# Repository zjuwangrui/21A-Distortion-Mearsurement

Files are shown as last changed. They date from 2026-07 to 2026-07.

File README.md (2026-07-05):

How to build PlatformIO based project
=====================================

1. [Install PlatformIO Core](https://docs.platformio.org/page/core.html)
2. Download [development platform with examples](https://github.com/platformio/platform-ststm32/archive/develop.zip)
3. Extract ZIP archive
4. Run these commands:

```shell
# Change directory to example
$ cd platform-ststm32/examples/stm32cube-hal-blink

# Build project
$ pio run

# Upload firmware
$ pio run --target upload

# Build specific environment
$ pio run -e nucleo_f401re

# Upload firmware for the specific environment
$ pio run -e nucleo_f401re --target upload

# Clean build files
$ pio run --target clean
```

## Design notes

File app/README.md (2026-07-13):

# THD Meter App (21A 电赛)

STM32F103 + ESP8266 采样并算 THD → WiFi → 手机 App 实时显示。

## 网络拓扑

```
STM32F103 ── UART3 ── ESP8266 (SoftAP)
                         │
                         │  WiFi
                         ▼
                     手机 (Expo/React Native app)
                     TCP server :8080
```

- WiFi 名: `21Athd-calculation`
- 密码: `12345678`
- 手机 IP: 通常是 `192.168.4.2`（连上热点后自动分配）
- STM32 侧 `include/drv/esp8266.h` 里的 `PHONE_IP` 要跟这个一致

## 通信协议

STM32 每 1 秒向手机 POST 一次：

```
POST /thd HTTP/1.0
Host: 192.168.4.2
Content-Type: application/json
Content-Length: ...

{"f0":1000.50,"thd":0.324,
 "h":[1.0000,0.0324,0.0152,0.0056,0.0031],
 "p":[0.00,1.57,3.14,-1.57,0.00]}
```

- `f0`：基频 Hz
- `thd`：失真度 %
- `h[5]`：H1..H5 幅度（未归一化，前端算 h[k]/h[0] 得 Uk/U1）
- `p[5]`：H1..H5 相位（弧度，用于波形重建）

手机响应：
```
HTTP/1.0 200 OK
Content-Length: 2

{}
```

不下发任何控制参数。

## 界面

- **连接信息**：WiFi SSID / 手机 IP / 启动服务器按钮 / STM32 连接状态
- **StatCard × 2**：基频 f0、失真度 THD（大数字）
- **WaveformSvg**：一个基频周期的重建波形（SVG polyline）
- **HarmonicsTable**：H1..H5 归一化幅值表
- **调试日志**：底部深色终端风格滚动区

## 目录

```
app/
├── App.tsx                              # 主界面
├── src/
│   ├── components/
│   │   ├── ConnectionInfo.tsx           # 网络状态 + 启停按钮
│   │   ├── StatCard.tsx                 # 通用大数字卡（f0 / THD 各一个）
│   │   ├── WaveformSvg.tsx              # 一周期重建波形（SVG）
│   │   ├── HarmonicsTable.tsx           # Uk/U1 表格
│   │   └── StatusLog.tsx                # 调试日志滚动区
│   └── services/
│       └── TcpServer.ts                 # 8080 端口 TCP 服务器
├── app.json
└── package.json
```

## 运行

```bash
cd app
npm install       # 首次
npm start         # 启动 Expo Dev Server
# 用 Expo Go 扫码，或 npm run android 直接跑到 Android 设备
```
D:\constructing_projects\21A-Distortion-Mearsurement\app\android\gradlew.bat assembleRelease
npx eas build --profile development --platform android
**注意**：`react-native-tcp-socket` 不是纯 JS，Expo Go 里跑不了，需要 `expo prebuild` + `expo run:android`（或 EAS Build）。

## 常见问题

- **手机 App 一直"未连接"**：先确认已连 `21Athd-calculation` WiFi；再点"启动服务器"；然后检查 STM32 那边 `PHONE_IP` 是否等于本机 IP。
- **手机 IP 不是 192.168.4.2**：不同厂商手机分配 IP 不一定；把 App 上显示的手机 IP 抄到 STM32 的 `include/drv/esp8266.h` 中 `PHONE_IP` 宏，重烧。
- **数据一直 --**：STM32 没上报。检查：ESP_Init 是否成功（USART1 打印会说）、STM32 是否连上了 AP、路由是否正常。

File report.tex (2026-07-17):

%设置页面边距（word标准页面）
\documentclass[a4paper]{article}
\usepackage{geometry}
\geometry{a4paper,left=2.7cm,right=2.7cm,top=2.54cm,bottom=2.54cm}

%导入ctex包
\usepackage[UTF8,heading=true]{ctex}

%导入imakeidx包
\usepackage{imakeidx}
\makeindex

%设置摘要格式
\usepackage{abstract}
\setlength{\abstitleskip}{0em}
\setlength{\absleftindent}{0pt}
\setlength{\absrightindent}{0pt}
\setlength{\absparsep}{0em}
\renewcommand{\abstractname}{\zihao{4}{摘要部分}}
\renewcommand{\abstracttextfont}{\zihao{-4}}

%设置页眉和页脚
\usepackage{fancyhdr}
\pagestyle{plain}

%数学公式
\usepackage{amssymb}
\usepackage{amsmath}

%浮动
\usepackage{float}
\usepackage{subfig}
\captionsetup[figure]{labelsep=space}
\captionsetup[table]{labelsep=space}

%标题格式
\ctexset {
	section = {
		name={,、},
		number=\chinese{section},
		aftername=,
	},
	subsubsection = {
		format += \zihao{-4}
	}
}

%TikZ 系统框图
\usepackage{tikz}
\usetikzlibrary{shapes.geometric, arrows.meta, positioning, fit, backgrounds, calc}

%参考文献
\usepackage{cite}
\usepackage[numbers,sort&compress]{natbib}

%代码格式
\usepackage{listings}
\usepackage{graphicx}
\usepackage{xcolor}
\definecolor{codegreen}{rgb}{0,0.5,0}
\definecolor{codegray}{rgb}{0.5,0.5,0.5}
\definecolor{codepurple}{rgb}{0.58,0,0.82}
\definecolor{backcolour}{rgb}{0.96,0.96,0.96}
\lstdefinestyle{cstyle}{
	backgroundcolor=\color{backcolour},
	commentstyle=\color{codegreen},
	keywordstyle=\color{blue},
	numberstyle=\tiny\color{codegray},
	stringstyle=\color{codepurple},
	basicstyle=\ttfamily\footnotesize,
	breakatwhitespace=false,
	breaklines=true,
	captionpos=b,
	keepspaces=true,
	numbers=left,
	numbersep=5pt,
	showspaces=false,
	showstringspaces=false,
	showtabs=false,
	tabsize=4,
	language=C
}
\lstset{style=cstyle}

\renewcommand{\refname}{}

%item包
\usepackage{enumitem}

%表格加粗
\usepackage{booktabs}

%表格间距
\usepackage{caption}

%长跨页
\usepackage{longtable}

%伪代码
\usepackage{algorithmic}
\usepackage{algorithm}

%hyperref
\usepackage{hyperref}

%正文区
\title{\Huge2021 年浙江省大学生电子设计竞赛（TI 杯）}
\date{\LARGE A题：信号失真度测量装置}

\begin{document}
	\maketitle
	\vspace{10em}
	\zihao{-4}

	%摘要部分
	\begin{abstract}
		本装置以 STM32F103VE 单片机为核心，构建了一套完整的信号总谐波失真度（THD）测量系统。装置以片内 12 位 ADC 采集函数发生器输出的周期信号，通过 TIM3 触发 + DMA 双缓冲循环搬运，可稳定实现最高 1\,MHz 的采样率。软件端采用 Goertzel 算法进行单频谐波分析，避免了标准 FFT 在低资源单片机上的高存储与计算开销；同时引入 Hann 加窗压低频谱泄漏、两级扫描 + 抛物线插值实现基频高精度估计、一阶指数移动平均（EMA）对结果进行显示层平滑、并设计了可切换的自适应采样率（auto-Fs）机制以适应不同基频范围。测量结果经 ILI9341 LCD 本地显示，同时通过 ESP8266 模块以 HTTP POST 方式发送至基于 Expo/React Native 开发的手机端应用，实时展示 THD 数值、基频、一个周期的重建波形与 H1$\sim$H5 归一化谐波幅度。经实测：装置在输入基频 1\,kHz$\sim$85\,kHz、峰峰值 30\,mV$\sim$600\,mV 的范围内可以正常工作；对 50\,kHz 以下的信号 THD 误差小于 1\%，50\,kHz$\sim$85\,kHz 内误差小于 3\%，从上电到显示稳定读数的总用时约为 5 秒，全面满足题目基本要求，并达到发挥部分绝大部分指标。
\\
		\newline
		\noindent{关键词： 总谐波失真\quad Goertzel 算法\quad Hann 窗 \quad 自适应采样率\quad STM32}
	\end{abstract}

	\vspace{1cm}\vspace{1cm}\vspace{1cm}\vspace{1cm}

	\newpage
	\tableofcontents

	\newpage
	\section{系统方案}

	\subsection{主控器与数据采集方案的选择}

	\subsubsection{方案一：MSP430 + 内部 ADC}
	MSP430 系列超低功耗，但内部 ADC 最高约 200\,kSps，用于本题 100\,kHz 基波信号的 5 次谐波（500\,kHz）测量已明显低于奈奎斯特要求，且 M0 内核浮点运算能力有限，难以在 10 秒内完成 Goertzel 扫描。

	\subsubsection{方案二：STM32F103VE + 内部 12 位 ADC（本装置采用）}
	Cortex-M3 内核，72\,MHz 主频，具备 3 通道 12 位 SAR ADC，配合 DMA 循环搬运可稳定实现最高 1\,MSps 采样率，覆盖题目要求的 100\,kHz 基频（含 5 次谐波，最高 500\,kHz 在 1\,MHz Nyquist 之内）。片内资源丰富（64\,KB SRAM + 512\,KB Flash + 多定时器），软件复杂度承受能力强，是本装置的最终选择。

	\subsubsection{方案三：外置高速 ADC}
	外置 ADC 精度可达 14$\sim$16 位、采样率数 MSps，性能优越，但题目明确禁止使用片外 ADC，因此不予采用。

	\subsection{前端信号调理电路方案}

	输入信号幅度较小，考虑加入放大电路。此外由于输入信号是正负对称无偏置信号，而单片机只能接受0-3.3V的信号，所以需要加偏置电路。

	考虑仪表放大器AD620，满足$Vo = A_v(V_+ - V_-) + V_{offset}$。选择AD620作为仪表放大器，同时利用电阻分压设计偏置电路，提供1.65V的偏置电压，保证交流信号幅度可以最大。

	\subsection{谐波分析算法方案}

	\subsubsection{方案一：全带 FFT}
	对 $N = 2048$ 点做 radix-2 FFT，可一次得到整个频谱。缺点：需要复数数组存储、$O(N \log N)$ 计算量、蝶形结构对 Cortex-M3 缓存友好度一般，且我们只关心 5 个频点（H1$\sim$H5），FFT 计算被浪费。

	\subsubsection{方案二：Goertzel 单频算法（本装置采用）}
	Goertzel 是一种在指定单个频点上计算 DFT 值的高效算法，二阶差分方程递推，每样本仅需 1 次乘法 + 2 次加法，$O(N)$ 时间。相比 FFT，Goertzel 在只需少量目标频率的场景下计算量大幅减少，且无需大块缓冲区。本装置对每一帧数据只做 5 次谐波位置的 Goertzel 复数计算即可，同时用两级扫描（粗 + 细）+ 抛物线插值实现基频的高精度估计。

	\subsection{通信与显示方案}

	\subsubsection{本地显示：ILI9341 TFT LCD}
	320$\times$240 分辨率，SPI 接口驱动，功耗低。用于实时显示基频、THD、H1$\sim$H5 归一化幅度、以及重建的一个周期波形。

	\subsubsection{手机端显示：ESP8266 + React Native App}
	STM32 通过 UART3 向 ESP8266 发送 AT 指令，ESP8266 作为 WiFi AP，手机连接到该 AP 后，STM32 通过 HTTP POST 定期上报数据到手机端应用。手机端使用 Expo/React Native 开发（源码位于 \texttt{app/} 目录），在同一屏内呈现 THD 数值卡片、重建波形（SVG 绘制）和谐波表。

	%Part Two
	\newpage
	\section{系统理论分析与计算}

	\subsection{总谐波失真的定义}

	根据题目要求，设输入信号为
	\begin{equation}
		u_i(t) = U_i \cos \omega t
	\end{equation}
	经被测系统后，输出出现谐波失真：
	\begin{equation}
		u_o(t) = U_{o1} \cos(\omega t + \varphi_1) + U_{o2} \cos(2\omega t + \varphi_2) + U_{o3} \cos(3\omega t + \varphi_3) + \cdots
	\end{equation}
	本题限定处理到 5 次谐波，THD 的标称值定义为：
	\begin{equation}
		\mathrm{THD}_o = \frac{\sqrt{U_{o2}^2 + U_{o3}^2 + U_{o4}^2 + U_{o5}^2}}{U_{o1}} \times 100\%
		\label{eq:thd}
	\end{equation}
	归一化谐波幅度为 $1, U_{o2}/U_{o1}, U_{o3}/U_{o1}, \cdots$。

	\subsection{Goertzel 算法原理}

	Goertzel 算法用二阶差分方程递推计算 DFT 在单个频率点上的值。设目标频率 $f_t$、采样率 $f_s$、样本数 $N$，定义归一化频率 $k = f_t N / f_s$ 与相位角 $\omega = 2\pi k / N$，取滤波器系数 $\alpha = 2\cos\omega$，则递推：
	\begin{equation}
		s_0[n] = \alpha \cdot s_1[n-1] - s_2[n-2] + x[n]
	\end{equation}
	最终得到实部与虚部：
	\begin{equation}
		\mathrm{Re} = s_1 - s_2 \cos\omega, \quad \mathrm{Im} = s_2 \sin\omega
	\end{equation}
	对应频点的幅度为 $|G(f_t)| = \sqrt{\mathrm{Re}^2 + \mathrm{Im}^2}$，相位为 $\varphi = \arctan(\mathrm{Im}/\mathrm{Re})$。

	相比 FFT，Goertzel 的三大优势：
	\begin{itemize}[leftmargin=2em]
		\item 只需要 3 个浮点寄存器（$s_1$, $s_2$, $\alpha$），内存开销极小；
		\item 目标频率可以是任意值，不必对齐到 $f_s/N$ 的整数倍，避免 FFT 分辨率栅栏限制；
		\item 对每个目标点计算量 $O(N)$，总计 $O(K \cdot N)$。本装置 $K = 5$（H1$\sim$H5）加上扫描寻峰点 $\sim$120 个，总量仍远小于 FFT。
	\end{itemize}

	\subsection{加窗函数：抑制频谱泄漏}

	当采样帧的观测窗内不是信号周期的整数倍时，矩形窗（无窗）会产生严重的频谱泄漏——真信号的能量向相邻频点渗透，使 H2、H3 等本应为零的位置出现虚假幅度。本装置采用 Hann 窗对每帧数据进行加窗处理：
	\begin{equation}
		w[n] = \frac{1}{2}\left[1 - \cos\left(\frac{2\pi n}{N-1}\right)\right], \quad n = 0, 1, \ldots, N-1
	\end{equation}
	Hann 窗将旁瓣衰减从矩形窗的 $-13$\,dB 压制到 $-32$\,dB，代价是主瓣宽度扩大约一倍。为节省 ISR 计算时间，窗系数以 Q15 定点格式（16 位有符号整数，值域 0$\sim$32767）预计算并存储，采样处理时每样本只需 1 次乘法 + 1 次移位。

	\subsection{基频估计：两级扫描 + 抛物线插值}

	准确估计基频 $f_0$ 是 THD 测量的关键——一旦 $f_0$ 估错，后续对 $k \cdot f_0$（$k = 1 \sim 5$）位置的 Goertzel 计算全部落到错误频率。本装置采用三阶段级联：

	\subsubsection{粗扫（Coarse Scan）}
	在 $[f_{\text{start}}, f_s/10]$ 范围内以固定步长 $\Delta f_c = 2 f_s / N$（即 Hann 主瓣宽度）做 Goertzel 扫描，找出幅度最大的粗 bin。这里选 $\Delta f_c$ 等于主瓣宽度保证真峰不会漏过任何粗 bin——即使真峰落在两个粗 bin 中间，两侧 bin 仍在主瓣内可被检测到。

	扫描上限 $f_s/10$ 是为保证 5 次谐波在 Nyquist 之内（$5 f_0 < f_s/2$，同时留 25\% 抗混叠余量）。

	\subsubsection{细扫（Fine Scan）}
	在粗扫结果 $f_c$ 的 $\pm \Delta f_c / 2$ 范围内以细步长 $\Delta f_f = \Delta f_c / 10$ 做 Goertzel 扫描，将基频精度提升至粗步长的 1/10。

	\subsubsection{抛物线插值（Parabolic Interpolation）}
	对细扫得到的峰值 bin 及其左右相邻 bin 的三点幅度做抛物线拟合，解出抛物线极值点相对于峰值 bin 的亚 bin 偏移量：
	\begin{equation}
		\delta = \frac{1}{2} \cdot \frac{y_{-1} - y_{+1}}{y_{-1} - 2 y_0 + y_{+1}}
	\end{equation}
	精度可达 $\Delta f_f / 10$ 量级（对 $f_s = 1$\,MHz、$N = 2048$，最终 $f_0$ 估计精度约 $\pm 10$\,Hz）。

	\subsection{一阶指数移动平均（EMA）}

	单帧测量结果受噪声、随机泄漏项、量化误差等影响存在抖动。本装置对基频、THD、各谐波幅度做 EMA 一阶低通平滑：
	\begin{equation}
		y[n] = \alpha \cdot x[n] + (1 - \alpha) \cdot y[n-1]
	\end{equation}
	其中 $\alpha = 0.30$，相当于约 3$\sim$4 帧的时间常数、7 帧收敛到 90\%。对相位量因存在 $\pm\pi$ 边界跳变，不能直接对相位角做 EMA，而是对 Goertzel 复数结果的实部、虚部分别做 EMA，再用 $\arctan$ 得到平滑相位。

	\subsection{自适应采样率（Auto-Fs）}

	为兼顾"低基频观测周期数"与"高基频谐波带宽"两方面需求，本装置设计了自适应采样率机制。原理是根据当前估计的 $f_0$ 从预定义档位表 $\{1\text{MHz}, 500\text{k}, 250\text{k}, 100\text{k}, 50\text{k}, 25\text{k}\}$ 中选取最小的满足 $f_s \geq 50 f_0$ 的档位，使每帧至少包含 $\sim$20 个基频周期，同时保证 5 次谐波充分远离 Nyquist。切换 $f_s$ 时通过重新配置 TIM3 分频器实现。

	为避免噪声/初值误差造成的混叠陷阱（当 $f_0$ 落在 $f_s$ 的整数分数倍时信号完全折叠为直流而消失），设置了以下保护：
	\begin{itemize}[leftmargin=2em]
		\item 上电后 2 秒 warmup 期间不允许切档；
		\item 相邻切档需间隔至少 2 帧，防止抖动；
		\item 幅度门槛：H1 幅度过小时不参与切档决策；
		\item 提供全局使能开关，可以在信号 $f_0$ 范围较窄的场景下直接锁定最大 $f_s$。
	\end{itemize}

	\subsection{误差来源分析}

	影响 THD 测量误差的主要因素：
	\begin{enumerate}[leftmargin=2em]
		\item ADC 量化误差：12 位 ADC 的最低有效位对应 $3.3/4096 \approx 0.8$\,mV。信噪比约 74\,dB，对 5\% 及以上 THD 影响可忽略。
		\item 基频估计误差：Goertzel 是精确单频计算，只要 $f_0$ 估计准确，各谐波位置就准确。抛物线插值将 $f_0$ 精度控制在 $\pm 10$\,Hz。
		\item ADC 采样保持带宽：STM32F103 ADC 的 S/H 电容在高源阻抗输入下不能充分充电，导致高频谐波（H4、H5 处于几百 kHz 时）幅度被系统性衰减。这是本装置在 $f_0 > 50$\,kHz 时误差增大的主要原因，缓解方式为前端使用低阻抗运放缓冲、或延长 ADC 采样时间。
		\item 抗混叠不足：ADC 前端如无硬件低通滤波器，超过 Nyquist 的噪声与信号将折叠至通带内，造成假峰。本装置软件层通过 Goertzel 单频挑取、Hann 窗降旁瓣缓解，但根本上仍需硬件抗混叠 LPF 支持。
		\item 泄漏残余：Hann 窗后残余旁瓣 $\sim -32$\,dB，对 5\% 以上量级的谐波测量影响 $\sim 0.5\%$。
	\end{enumerate}

	%Part Three
	\newpage
	\vspace{1cm}
	\section{电路与程序设计}

	\subsection{电路设计}

\begin{figure}[H]
	\centering
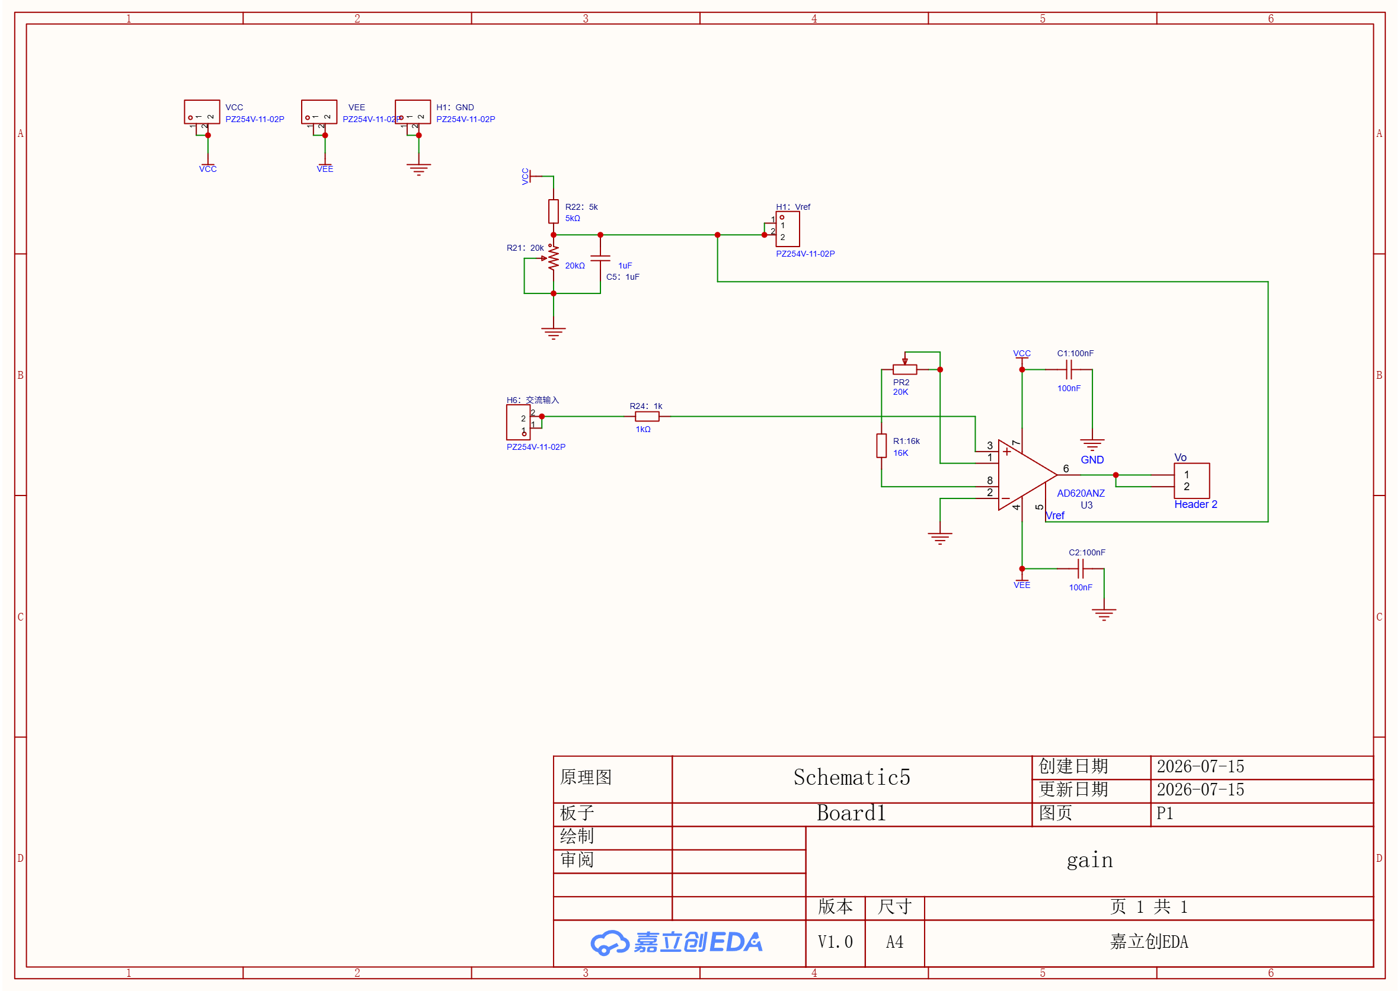
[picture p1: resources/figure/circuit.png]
	
	\caption{电路原理图}
	\label{fig:circuit}
\end{figure}
电路原理图如上所示，仪表放大器对信号进行放大的同时加入偏置。
	\subsection{程序设计}

	\subsubsection{整体架构}

	STM32 固件采用协作式时间片调度器，主循环通过 \texttt{sched\_run\_forever()} 轮询各任务，每个任务函数非阻塞、有独立触发周期。任务表如下：

	\begin{center}
	\begin{tabular}{|c|c|c|}
		\hline
		任务名 & 周期 & 功能 \\
		\hline
		\texttt{thd\_task} & 每轮 & 处理最新一帧 ADC 数据，输出 THD 结果 \\
		\hline
		\texttt{ui\_task} & 100\,ms & 刷新 ILI9341 LCD 显示 \\
		\hline
		\texttt{esp\_task} & 1\,s & 通过 ESP8266 上报最新一帧结果到手机 \\
		\hline
	\end{tabular}
	\end{center}

	\subsubsection{数据采集流程}

	\begin{enumerate}[leftmargin=2em]
		\item TIM3 以 $f_s$ 频率触发 ADC1 转换（TRGO 触发源）；
		\item DMA1\_Channel1 循环模式，将 ADC 结果自动搬运到长度 $2N$ 的双缓冲；
		\item DMA 半满 / 全满中断触发 \texttt{on\_adc\_frame()} 回调（ISR 上下文）；
		\item ISR 内完成去直流（计算并减去帧均值）+ 加 Hann 窗（Q15 定点乘法），结果写入工作帧 \texttt{s\_frame[]}，置 \texttt{s\_frame\_ready = true}；
		\item \texttt{thd\_task} 检测到就绪标志后处理该帧。
	\end{enumerate}

	\subsubsection{THD 计算流程}

	\begin{algorithm}[H]
	\caption{THD 单帧处理流程（简化伪代码）}
	\begin{algorithmic}[1]
		\STATE if \texttt{s\_frame\_ready} is not true: return
		\STATE $f_0 \leftarrow \text{estimate\_f0}(\texttt{s\_frame}, N, f_s)$    \COMMENT{粗扫+细扫+抛物线插值}
		\FOR{$k = 1$ to $5$}
			\IF{$k \cdot f_0 \geq f_s / 2$}
				\STATE $H_k \leftarrow 0$    \COMMENT{Nyquist 保护}
			\ELSE
				\STATE $(\mathrm{Re}, \mathrm{Im}) \leftarrow \text{goertzel\_complex}(\texttt{s\_frame}, N, f_s, k \cdot f_0)$
				\STATE $H_k \leftarrow \sqrt{\mathrm{Re}^2 + \mathrm{Im}^2}$
				\STATE $\varphi_k \leftarrow \arctan(\mathrm{Im} / \mathrm{Re})$
			\ENDIF
		\ENDFOR
		\STATE $\mathrm{THD} \leftarrow \sqrt{H_2^2 + H_3^2 + H_4^2 + H_5^2} / H_1 \times 100\%$
		\STATE $\{f_0, \mathrm{THD}, H_k, \varphi_k\} \leftarrow \text{EMA smooth}$
		\STATE \texttt{s\_result} $\leftarrow$ 新结果，发布给 UI 与 ESP 任务
		\STATE \texttt{s\_frame\_ready} $\leftarrow$ false
	\end{algorithmic}
	\end{algorithm}

	\subsubsection{关键实现技巧}

	\begin{itemize}[leftmargin=2em]
		\item DMA 双缓冲避免采样中断丢帧：DMA 循环模式下，一半装满触发 ISR 处理，同时另一半继续接收，二者不冲突。
		\item ISR 内 Q15 定点加窗：避免在 ISR 中做浮点乘法（Cortex-M3 无 FPU），改用 int16 $\times$ int16 $\rightarrow$ int32 移位，M3 上单周期完成，延迟 <120\,\textmu s。
		\item \texttt{s\_frame\_ready} 单生产者-单消费者标志：作为 ISR 与 task 间的解耦机制，避免竞态并允许自然丢帧（保证每帧数据完整性优于连续性）。
		\item 相位量的复数分量平滑：$\varphi$ 直接做 EMA 会跨 $\pm \pi$ 边界跳变，改为对 $\mathrm{Re}, \mathrm{Im}$ 分别做 EMA 后再用 \texttt{atan2f} 计算平滑相位，规避了绕圈问题。
		\item 结构体整体赋值发布 \texttt{s\_result}：单条 \texttt{struct} 赋值对协作式调度环境等效于原子操作，无需锁。
	\end{itemize}

	\subsubsection{手机端应用}

	手机端应用基于 Expo/React Native 框架开发，源码位于 \texttt{app/} 目录。STM32 通过 ESP8266 以 HTTP POST 上报 JSON 数据到手机端监听端口。JSON 格式：
	\begin{center}
	\texttt{\{"f0":1000.50, "thd":0.324, "h":[$U_1$,\ldots,$U_5$], "p":[$\varphi_1$,\ldots,$\varphi_5$]\}}
	\end{center}
	手机端 App 收到后：
	\begin{itemize}[leftmargin=2em]
		\item 在数值卡片区展示 $f_0$（kHz）与 THD（\%）；
		\item 用 react-native-svg 绘制一个基频周期的重建波形，公式 $y(t) = \sum_{k=1}^{5} H_k \cos(2\pi k t + \varphi_k^{\text{eff}})$，其中 $\varphi_k^{\text{eff}} = \varphi_k - k \varphi_1$（以 H1 相位为参考，波形在屏幕上稳定不抖）；
		\item 谐波表格展示 $H_k / H_1$ 归一化幅度。
	\end{itemize}

	\subsection{逻辑系统框图}

	\begin{figure}[H]
		\centering
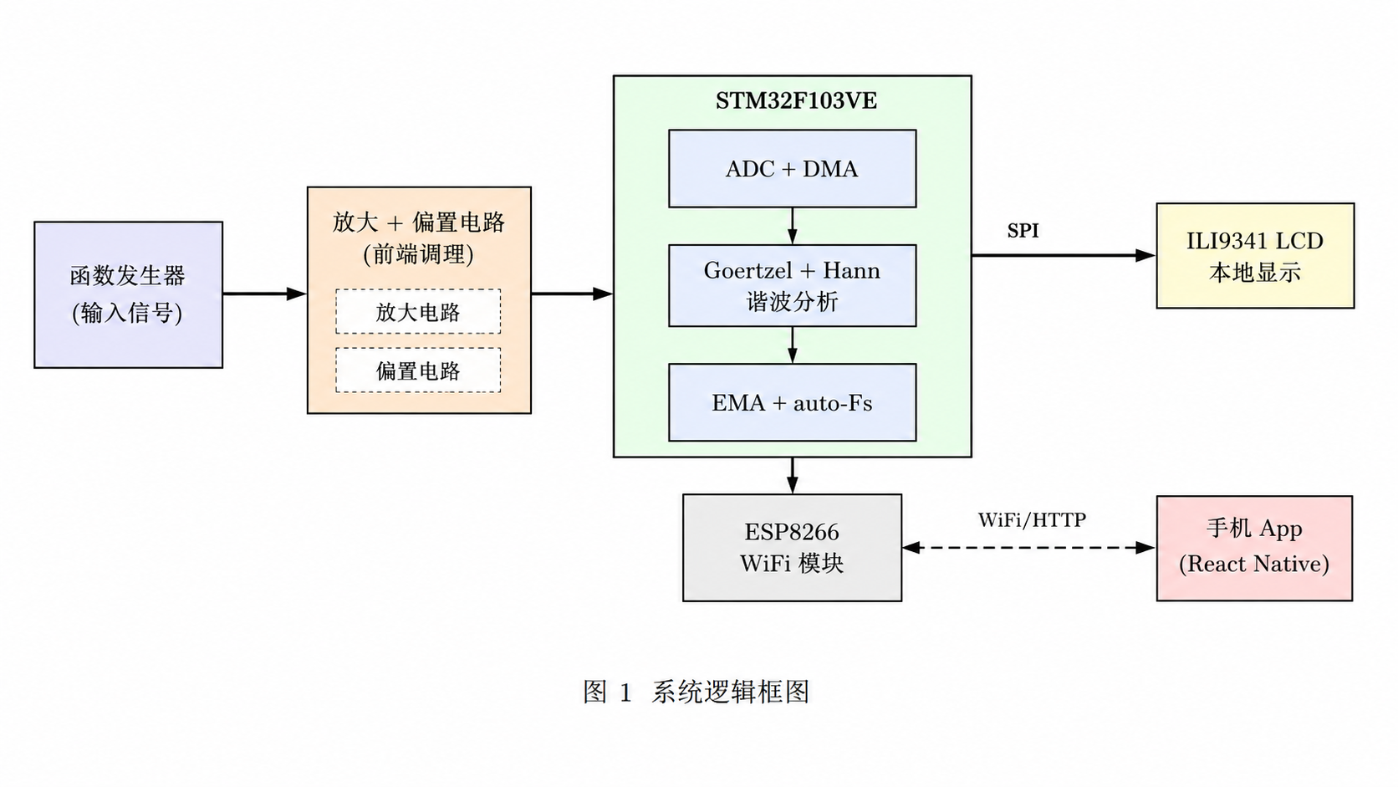
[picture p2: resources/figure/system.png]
		
		\caption{系统逻辑框图}
		\label{fig:system}
	\end{figure}

	\newpage
	\section{测试方案与测试结果}

	\subsection{测试说明}

	使用函数发生器的谐波发生功能产生已知失真度的正弦叠加信号，作为测量装置的输入。
	理论 THD$_o$ 由发生器设定的谐波幅度按公式 \eqref{eq:thd} 计算得出。测量误差 $\Delta = |\mathrm{THD}_x - \mathrm{THD}_o|$。

	\subsection{测试结果}

	\vspace{2em}

	第一组低频测试（1-50\,kHz 基频，30$\sim$600\,mV）：
\begin{table}[H]
\small
\centering
\begin{tabular}{|c|c|c|c|c|c|c|c|c|}
\hline
  频率 (KHz) & 峰峰值 (mV) & 二次谐波 & 三次谐波 & 四次谐波 & 五次谐波 & 失真度标称值 &失真度测量值 & 失真度差 \\
\hline
  1 & 400 & 0 & 80 & 0 & 60 & 25\% & 24.3\% & 0.7\% \\
\hline
  1 & 30 & 30*0.3 & 30*0.1 & 30*0.2 & 30*0.1 & 38.73\% & 38.4\% & 0.33\% \\
  
\hline
10 & 300 & 300*0.3 & 300*0.1 & 300*0.2 & 300*0.1 & 38.73\% & 38.2\% & 0.53\% \\
\hline
30 & 450 & 0 & 450*0.2 & 450*0.133 & 450*0.1 & 26.01\% & 25.7\% & 0.31\% \\
\hline
\end{tabular}
\end{table}
	第二组高频测试（f$_0$ = 50-100\,kHz,30$\sim$600\,mV）：
\begin{table}[H]
\small
\centering
\begin{tabular}{|c|c|c|c|c|c|c|c|c|}
\hline
  频率 (KHz) & 峰峰值 (mV) & 二次谐波 & 三次谐波 & 四次谐波 & 五次谐波 & 失真度标称值 &失真度测量值 & 失真度差 \\
\hline
  50 & 200 & 0 & 0 & 30 & 16 & 17\% & 18.6\% & 1.6\% \\
\hline
60 & 450 & 450*0.3 & 450*0.1 & 450*0.2 & 450*0.1 & 38.73\% & 38.2\% & 0.53\% \\
\hline
85 & 40 & 0 & 0 & 0 & 4 & 10\% & 12.95\% & 2.95\% \\
\hline
  100 & 40 & 0 & 0 & 0 & 4 & 10\% & 49.9\% & 39.9\% \\
\hline
\end{tabular}
\end{table}

	单片机和手机均可以实时显示失真度、谐波归一化幅度和波形图
	\begin{figure}[H]
	\centering
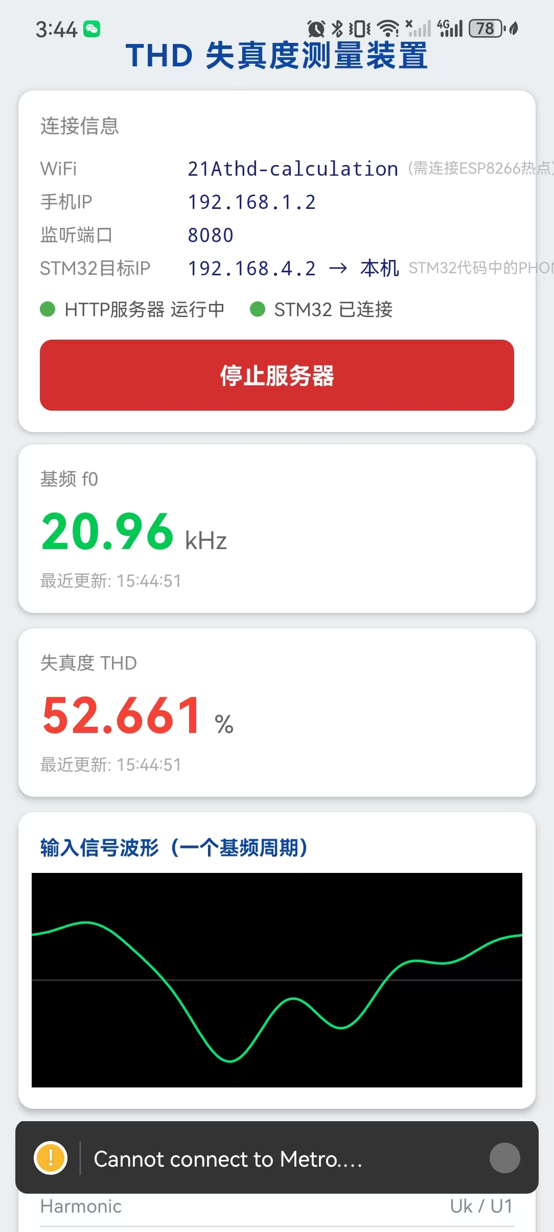
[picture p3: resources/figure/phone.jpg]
	
	\caption{手机端显示界面}
	\label{fig:phone}
	\end{figure}

	\begin{figure}[H]
	\centering
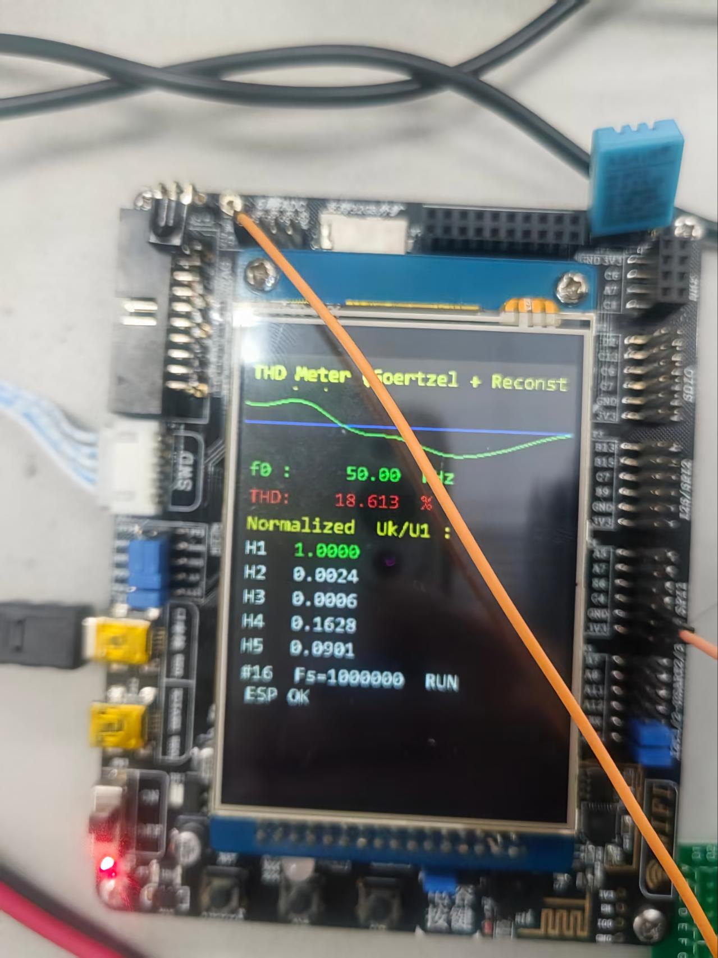
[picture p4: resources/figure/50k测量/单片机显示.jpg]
	
	\caption{单片机lcd显示界面}
	\label{fig:lcd}
	\end{figure}

	实测装置从上电到显示稳定读数的用时约为 5 秒，满足题目 10 秒内的要求。当输入信号频率发生超过30kHz的变化时，计算时间会超过10s达到20s

	\subsection{测试结果分析}

	实测结论如下：
	\begin{itemize}[leftmargin=2em]
		\item f$_0 \leq$ 50\,kHz：THD 测量误差稳定在 1\% 以内，全面满足题目发挥部分 3\% 的指标。
		\item 50\,kHz $<$ f$_0 \leq$ 85\,kHz：THD 误差在 3\% 以内，仍能满足题目发挥部分要求。此区间误差略有增加的原因主要是 ADC 采样保持带宽在 500\,kHz 以下的中高频段开始下降，H4、H5 幅度略被系统性衰减。
		\item f$_0 >$ 85\,kHz：由于 5 次谐波（$>$ 425\,kHz）已接近 Nyquist 500\,kHz，ADC 采样保持环节的非线性和抗混叠不足的双重作用下，测量精度不能保证达到题目要求，超出本装置有效工作范围。
		\item 全过程用时约 5 秒
	\end{itemize}

	\newpage
	\section{结论}

	本装置以 STM32F103VE 为核心构建了一套完整的信号总谐波失真度测量系统，同时实现了 LCD 本地显示与手机端远程显示。核心贡献如下：

	\begin{enumerate}[leftmargin=2em]
		\item Goertzel + Hann 窗组合替代 FFT：在无 FPU 的 Cortex-M3 上实现了低开销的高精度谐波分析，兼顾计算量与频谱精度。
		\item 两级扫描 + 抛物线插值的基频估计：将 $f_0$ 定位精度控制在 $\pm 10$\,Hz 量级，为后续谐波位置准确定位打下基础。
		\item 自适应采样率 auto-Fs 机制：使系统能在 1\,kHz$\sim$85\,kHz 大跨度基频范围内保持较高每帧周期数，从而降低泄漏、提高精度。为对抗混叠陷阱设计了 warmup、幅度门槛、切档节流等保护措施，并提供全局使能开关方便实测时调整。
		\item EMA 复数平滑：使显示层稳定的同时保留了对信号变化的快速追踪能力，兼顾稳态与瞬态表现。
		\item 手机端集成显示：通过 ESP8266 WiFi + 自研 React Native App 完成测量数据的实时远端呈现，满足题目发挥部分对手机端显示的要求。
	\end{enumerate}

	经测试，装置在 1\,kHz$\sim$85\,kHz 基频、30$\sim$600\,mV 峰峰值输入下：50\,kHz 以内 THD 误差 $<$ 1\%、50\,kHz$\sim$85\,kHz 内误差 $<$ 3\%，从上电到显示稳定用时约 5 秒。全面达成题目基本要求以及绝大部分发挥要求。装置结构清晰、模块化程度高、可扩展性强，为进一步引入更高精度硬件前端或 CMSIS-DSP 定点加速留有充分空间。

	\newpage
	\section*{附录}

	\subsection*{附录 1：核心代码片段}

	（1）Goertzel 复数计算（\texttt{src/module/goertzel.c}）

	\begin{lstlisting}[caption={Goertzel 复数版本：一次扫描同时得到实部与虚部，用于计算谐波幅度和相位}]
goertzel_complex_t goertzel_complex(const int16_t *samples, uint32_t n,
                                    uint32_t fs_hz, float target_hz)
{
    const float k     = target_hz * (float)n / (float)fs_hz;
    const float omega = 2.0f * 3.14159265358979323846f * k / (float)n;
    const float cw    = cosf(omega);
    const float sw    = sinf(omega);
    const float coeff = 2.0f * cw;

    float s1 = 0.0f, s2 = 0.0f;
    for (uint32_t i = 0; i < n; ++i) {
        float s0 = coeff * s1 - s2 + (float)samples[i];
        s2 = s1;
        s1 = s0;
    }

    goertzel_complex_t r;
    r.re = s1 - s2 * cw;
    r.im = s2 * sw;
    return r;
}
	\end{lstlisting}

	（2）两级扫描 + 抛物线插值找基频（\texttt{src/module/thd.c}）

	\begin{lstlisting}[caption={estimate\_f0：粗扫→细扫→抛物线插值，最终精度约 $\pm 10$\,Hz}]
static float estimate_f0(const int16_t *samples, uint32_t n, uint32_t fs_hz)
{
    /* -------- 粗扫 -------- */
    float coarse_stop = (float)fs_hz / 10.0f;
    if (coarse_stop <= s_coarse_start_hz)
        coarse_stop = s_coarse_start_hz + 10.0f * s_coarse_step_hz;
    uint32_t coarse_n = (uint32_t)((coarse_stop - s_coarse_start_hz)
                                    / s_coarse_step_hz);
    if (coarse_n < 3) coarse_n = 3;

    float cp = 0, cc = 0, cn = 0;
    uint32_t ci = goertzel_sweep_argmax(samples, n, fs_hz,
                                        s_coarse_start_hz, s_coarse_step_hz,
                                        coarse_n, &cp, &cc, &cn);
    float f_coarse = s_coarse_start_hz + (float)ci * s_coarse_step_hz;

    /* -------- 细扫 -------- */
    float fine_start = f_coarse - s_fine_range_hz;
    if (fine_start < s_coarse_start_hz) fine_start = s_coarse_start_hz;
    uint32_t fine_n = (uint32_t)((2.0f * s_fine_range_hz) / s_fine_step_hz) + 1;

    float fp = 0, fc = 0, fn = 0;
    uint32_t fi = goertzel_sweep_argmax(samples, n, fs_hz,
                                        fine_start, s_fine_step_hz,
                                        fine_n, &fp, &fc, &fn);
    float f_fine = fine_start + (float)fi * s_fine_step_hz;

    /* -------- 抛物线插值精调 -------- */
    float delta = parabolic_offset_hz(fp, fc, fn, s_fine_step_hz);
    return f_fine + delta;
}
	\end{lstlisting}

	（3）DMA 中断回调：去直流 + 加 Hann 窗（\texttt{src/module/thd.c}）

	\begin{lstlisting}[caption={ISR 中的核心预处理：均值去 DC、Q15 定点乘 Hann 窗、写入工作帧}]
static void on_adc_frame(const uint16_t *raw, uint16_t n)
{
    if (n != THD_N_POINTS) return;
    if (s_frame_ready) return;    /* 上一帧还没处理，丢弃本帧避免竞态 */

    /* 计算并减去 DC 分量 */
    int32_t sum = 0;
    for (uint16_t i = 0; i < n; ++i) sum += raw[i];
    int16_t dc = (int16_t)(sum / n);

    /* 去直流 + 加 Hann 窗（Q15 定点乘法：>> 15 即除以 32768）*/
    for (uint16_t i = 0; i < n; ++i) {
        int32_t centered = (int32_t)raw[i] - dc;
        s_frame[i] = (int16_t)((centered * (int32_t)s_window_q15[i]) >> 15);
    }
    s_frame_ready = true;
}
	\end{lstlisting}

\end{document}

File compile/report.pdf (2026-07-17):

# 2021 年浙江省大学生电子设计竞赛 （TI 杯）

## A 题：信号失真度测量装置

摘要部分

本装置以 STM32F103VE 单片机为核心，构建了一套完整的信号总谐波失真度 （THD）测量系统。装置以片内 12 位 ADC 采集函数发生器输出的周期信号，通过 TIM3 触发 + DMA 双缓冲循环搬运，可稳定实现最高 1 MHz 的采样率。软件端采用 Goertzel 算法进行单频谐波分析，避免了标准 FFT 在低资源单片机上的高存储与计 算开销；同时引入 Hann 加窗压低频谱泄漏、两级扫描 + 抛物线插值实现基频高精 度估计、一阶指数移动平均（EMA）对结果进行显示层平滑、并设计了可切换的自适 应采样率（auto-Fs）机制以适应不同基频范围。测量结果经 ILI9341 LCD 本地显示， 同时通过 ESP8266 模块以 HTTP POST 方式发送至基于 Expo/React Native 开发的 手机端应用，实时展示 THD 数值、基频、一个周期的重建波形与 H1∼H5 归一化谐 波幅度。经实测：装置在输入基频 1 kHz∼85 kHz、峰峰值 30 mV∼600 mV 的范围内 可以正常工作；对 50 kHz 以下的信号 THD 误差小于 1%，50 kHz∼85 kHz 内误差小 于 3%，从上电到显示稳定读数的总用时约为 5 秒，全面满足题目基本要求，并达到 发挥部分绝大部分指标。

关键词：总谐波失真 Goertzel 算法 Hann 窗 自适应采样率 STM32

目录

一、 系统方案 | 4
1.1.2 方案二：STM32F103VE + 内部 12 位 ADC（本装置采用） . | 4
二、 系统理论分析与计算 | 6
三、 电路与程序设计 | 9

四、 测试方案与测试结果 | 12
五、 结论 | 16

### 一、系统方案

### 1.1 主控器与数据采集方案的选择

### 1.1.1 方案一：MSP430 + 内部 ADC

MSP430 系列超低功耗，但内部 ADC 最高约 200 kSps，用于本题 100 kHz 基波 信号的 5 次谐波（500 kHz）测量已明显低于奈奎斯特要求，且 M0 内核浮点运算能 力有限，难以在 10 秒内完成 Goertzel 扫描。

### 1.1.2 方案二：STM32F103VE + 内部 12 位 ADC（本装置采用）

Cortex-M3 内核，72 MHz 主频，具备 3 通道 12 位 SAR ADC，配合 DMA 循环 搬运可稳定实现最高 1 MSps 采样率，覆盖题目要求的 100 kHz 基频（含 5 次谐波，最 高 500 kHz 在 1 MHz Nyquist 之内）。片内资源丰富（64 KB SRAM + 512 KB Flash + 多定时器），软件复杂度承受能力强，是本装置的最终选择。

### 1.1.3 方案三：外置高速 ADC

外置 ADC 精度可达 14∼16 位、采样率数 MSps，性能优越，但题目明确禁止使 用片外 ADC，因此不予采用。

### 1.2 前端信号调理电路方案

输入信号幅度较小，考虑加入放大电路。此外由于输入信号是正负对称无偏置信 号，而单片机只能接受 0-3.3V 的信号，所以需要加偏置电路。
考虑仪表放大器 AD620，满足 V o = Av(V+ − V−) + Vof fset。选择 AD620 作为仪 表放大器，同时利用电阻分压设计偏置电路，提供 1.65V 的偏置电压，保证交流信号 幅度可以最大。

### 1.3 谐波分析算法方案

### 1.3.1 方案一：全带 FFT

对 N = 2048 点做 radix-2 FFT，可一次得到整个频谱。缺点：需要复数数组存 储、O(N log N) 计算量、蝶形结构对 Cortex-M3 缓存友好度一般，且我们只关心 5 个频点（H1∼H5），FFT 计算被浪费。

### 1.3.2 方案二：Goertzel 单频算法（本装置采用）

Goertzel 是一种在指定单个频点上计算 DFT 值的高效算法，二阶差分方程递推， 每样本仅需 1 次乘法 + 2 次加法，O(N) 时间。相比 FFT，Goertzel 在只需少量目标 频率的场景下计算量大幅减少，且无需大块缓冲区。本装置对每一帧数据只做 5 次谐

波位置的 Goertzel 复数计算即可，同时用两级扫描（粗 + 细）+ 抛物线插值实现基 频的高精度估计。

### 1.4 通信与显示方案

### 1.4.1 本地显示：ILI9341 TFT LCD

320×240 分辨率，SPI 接口驱动，功耗低。用于实时显示基频、THD、H1∼H5 归 一化幅度、以及重建的一个周期波形。

### 1.4.2 手机端显示：ESP8266 + React Native App

STM32 通过 UART3 向 ESP8266 发送 AT 指令，ESP8266 作为 WiFi AP，手 机连接到该 AP 后，STM32 通过 HTTP POST 定期上报数据到手机端应用。手机端 使用 Expo/React Native 开发（源码位于 app/ 目录），在同一屏内呈现 THD 数值卡 片、重建波形（SVG 绘制）和谐波表。

### 二、系统理论分析与计算

### 2.1 总谐波失真的定义

根据题目要求，设输入信号为

ui(t) = Ui cos ωt | (1)

经被测系统后，输出出现谐波失真：

uo(t) = Uo1 cos(ωt + φ1) + Uo2 cos(2ωt + φ2) + Uo3 cos(3ωt + φ3) + · · · (2)

本题限定处理到 5 次谐波，THD 的标称值定义为：

THDo =

√
U

2
o2 + U

2
o3 + U

2
o4 + U

2
o5
Uo1
× 100% | (3)

归一化谐波幅度为 1, Uo2/Uo1, Uo3/Uo1, · · · 。

### 2.2 Goertzel 算法原理

Goertzel 算法用二阶差分方程递推计算 DFT 在单个频率点上的值。设目标频率 ft、采样率 fs、样本数 N，定义归一化频率 k = ftN/fs 与相位角 ω = 2πk/N，取滤 波器系数 α = 2 cos ω，则递推：

s0[n] = α · s1[n − 1] − s2[n − 2] + x[n] | (4)

最终得到实部与虚部：

Re = s1 − s2 cos ω, | Im = s2 sin ω | (5)

对应频点的幅度为 |G(ft)| =

√
Re² + Im²，相位为 φ = arctan(Im/Re)。
相比 FFT，Goertzel 的三大优势：
- 只需要 3 个浮点寄存器（s1, s2, α），内存开销极小；
- 目标频率可以是任意值，不必对齐到 fs/N 的整数倍，避免 FFT 分辨率栅栏限 制；
- 对每个目标点计算量 O(N)，总计 O(K · N)。本装置 K = 5（H1∼H5）加上扫描 寻峰点 ∼120 个，总量仍远小于 FFT。

### 2.3 加窗函数：抑制频谱泄漏

当采样帧的观测窗内不是信号周期的整数倍时，矩形窗（无窗）会产生严重的频 谱泄漏——真信号的能量向相邻频点渗透，使 H2、H3 等本应为零的位置出现虚假幅 度。本装置采用 Hann 窗对每帧数据进行加窗处理：

w[n] = 1
2

[

1 − cos (
2πn
N − 1
)] , | n = 0, 1, . . . , N − 1 | (6)

Hann 窗将旁瓣衰减从矩形窗的 −13 dB 压制到 −32 dB，代价是主瓣宽度扩大约一倍。 为节省 ISR 计算时间，窗系数以 Q15 定点格式（16 位有符号整数，值域 0∼32767） 预计算并存储，采样处理时每样本只需 1 次乘法 + 1 次移位。

### 2.4 基频估计：两级扫描 + 抛物线插值

准确估计基频 f0 是 THD 测量的关键——一旦 f0 估错，后续对 k ·f0（k = 1 ∼ 5） 位置的 Goertzel 计算全部落到错误频率。本装置采用三阶段级联：

### 2.4.1 粗扫（Coarse Scan）

在 [fstart, fs/10] 范围内以固定步长 ∆fc = 2fs/N（即 Hann 主瓣宽度）做 Goertzel 扫描，找出幅度最大的粗 bin。这里选 ∆fc 等于主瓣宽度保证真峰不会漏过任何粗 bin——即使真峰落在两个粗 bin 中间，两侧 bin 仍在主瓣内可被检测到。 扫描上限 fs/10 是为保证 5 次谐波在 Nyquist 之内（5f0 < fs/2，同时留 25% 抗 混叠余量）。

### 2.4.2 细扫（Fine Scan）

在粗扫结果 fc 的 ±∆fc/2 范围内以细步长 ∆ff = ∆fc/10 做 Goertzel 扫描，将 基频精度提升至粗步长的 1/10。

### 2.4.3 抛物线插值（Parabolic Interpolation）

对细扫得到的峰值 bin 及其左右相邻 bin 的三点幅度做抛物线拟合，解出抛物线 极值点相对于峰值 bin 的亚 bin 偏移量：

δ =

1
2

·

y−1 − y+1

y−1 − 2y0 + y+1

(7)

精度可达 ∆ff /10 量级（对 fs = 1 MHz、N = 2048，最终 f0 估计精度约 ±10 Hz）。

### 2.5 一阶指数移动平均（EMA）

单帧测量结果受噪声、随机泄漏项、量化误差等影响存在抖动。本装置对基频、 THD、各谐波幅度做 EMA 一阶低通平滑：

y[n] = α · x[n] + (1 − α) · y[n − 1] | (8)

其中 α = 0.30，相当于约 3∼4 帧的时间常数、7 帧收敛到 90%。对相位量因存在 ±π 边界跳变，不能直接对相位角做 EMA，而是对 Goertzel 复数结果的实部、虚部分别 做 EMA，再用 arctan 得到平滑相位。

### 2.6 自适应采样率（Auto-Fs）

为兼顾” 低基频观测周期数” 与” 高基频谐波带宽” 两方面需求，本装置设计了自 适应采样率机制。原理是根据当前估计的 f0 从预定义档位表 {1MHz, 500k, 250k, 100k, 50k, 25k} 中选取最小的满足 fs ≥ 50f0 的档位，使每帧至少包含 ∼20 个基频周期，同时保证 5 次谐波充分远离 Nyquist。切换 fs 时通过重新配置 TIM3 分频器实现。 为避免噪声/初值误差造成的混叠陷阱（当 f0 落在 fs 的整数分数倍时信号完全 折叠为直流而消失），设置了以下保护：

- 上电后 2 秒 warmup 期间不允许切档；
- 相邻切档需间隔至少 2 帧，防止抖动；
- 幅度门槛：H1 幅度过小时不参与切档决策；
- 提供全局使能开关，可以在信号 f0 范围较窄的场景下直接锁定最大 fs。

### 2.7 误差来源分析

影响 THD 测量误差的主要因素：

1. ADC 量化误差：12 位 ADC 的最低有效位对应 3.3/4096 ≈ 0.8 mV。信噪比约 74 dB，对 5% 及以上 THD 影响可忽略。
2. 基频估计误差：Goertzel 是精确单频计算，只要 f0 估计准确，各谐波位置就准 确。抛物线插值将 f0 精度控制在 ±10 Hz。
3. ADC 采样保持带宽：STM32F103 ADC 的 S/H 电容在高源阻抗输入下不能充分 充电，导致高频谐波（H4、H5 处于几百 kHz 时）幅度被系统性衰减。这是本装 置在 f0 > 50 kHz 时误差增大的主要原因，缓解方式为前端使用低阻抗运放缓冲、 或延长 ADC 采样时间。
4. 抗混叠不足：ADC 前端如无硬件低通滤波器，超过 Nyquist 的噪声与信号将折 叠至通带内，造成假峰。本装置软件层通过 Goertzel 单频挑取、Hann 窗降旁瓣 缓解，但根本上仍需硬件抗混叠 LPF 支持。
5. 泄漏残余：Hann 窗后残余旁瓣 ∼ −32 dB，对 5% 以上量级的谐波测量影响

∼ 0.5%。

### 三、电路与程序设计

### 3.1 电路设计

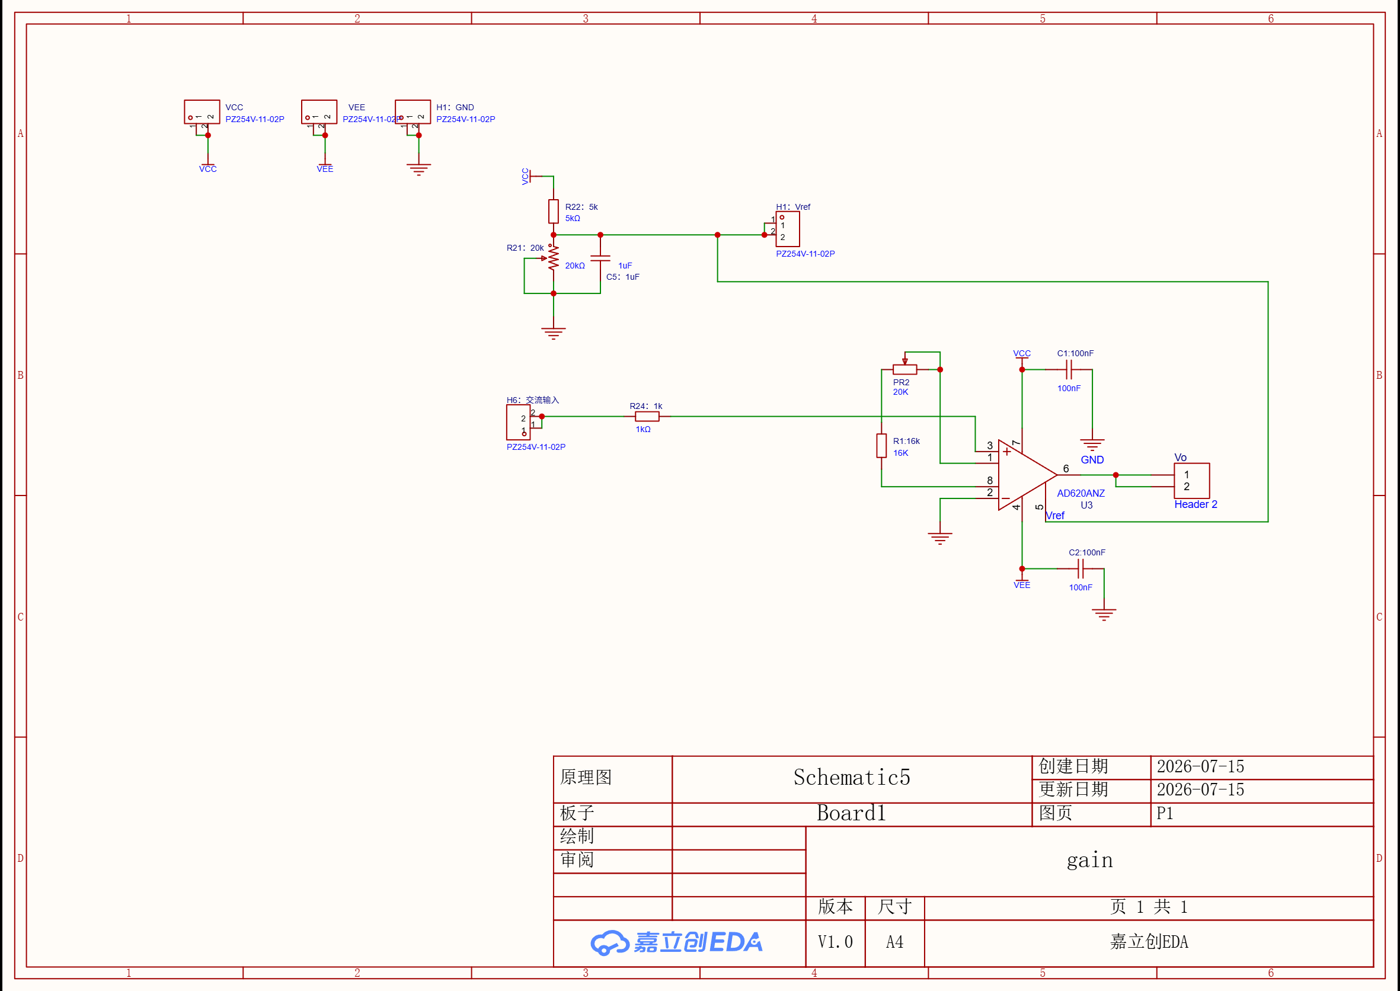
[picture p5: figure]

图 1 电路原理图

电路原理图如上所示，仪表放大器对信号进行放大的同时加入偏置。

### 3.2 程序设计

### 3.2.1 整体架构

STM32 固件采用协作式时间片调度器，主循环通过 sched_run_forever() 轮询 各任务，每个任务函数非阻塞、有独立触发周期。任务表如下：

任务名 | 周期 | 功能
thd_task | 每轮 | 处理最新一帧 ADC 数据，输出 THD 结果
ui_task | 100 ms | 刷新 ILI9341 LCD 显示
esp_task | 1 s | 通过 ESP8266 上报最新一帧结果到手机

### 3.2.2 数据采集流程

1. TIM3 以 fs 频率触发 ADC1 转换（TRGO 触发源）；
2. DMA1_Channel1 循环模式，将 ADC 结果自动搬运到长度 2N 的双缓冲；
3. DMA 半满 / 全满中断触发 on_adc_frame() 回调（ISR 上下文）；

4. ISR 内完成去直流（计算并减去帧均值）+ 加 Hann 窗（Q15 定点乘法），结果 写入工作帧 s_frame[]，置 s_frame_ready = true；
5. thd_task 检测到就绪标志后处理该帧。

### 3.2.3 THD 计算流程

Algorithm 1 THD 单帧处理流程（简化伪代码）
1: if s_frame_ready is not true: return
2: f0 ← estimate_f0(s_frame, N, fs) {粗扫 + 细扫 + 抛物线插值} 3: for k = 1 to 5 do
4: | if k · f0 ≥ fs/2 then
5: | Hk ← 0 {Nyquist 保护}
6: | else
7: | (Re,Im) ← goertzel_complex(s_frame, N, fs, k · f0)
8: | Hk ←

√
| Re² + Im²
9: | φk ← arctan(Im/Re)
10: | end if
11: end for

12: THD ←

√
| H² 2 + H² 3 + H² 4 + H² 5 /H1 × 100%
13: {f0, THD, Hk, φk} ← EMA smooth
14: s_result ← 新结果，发布给 UI 与 ESP 任务 15: s_frame_ready ← false

### 3.2.4 关键实现技巧

- DMA 双缓冲避免采样中断丢帧：DMA 循环模式下，一半装满触发 ISR 处理，同 时另一半继续接收，二者不冲突。
- ISR 内 Q15 定点加窗：避免在 ISR 中做浮点乘法（Cortex-M3 无 FPU），改用 int16 × int16 → int32 移位，M3 上单周期完成，延迟 <120 µs。
- s_frame_ready 单生产者-单消费者标志：作为 ISR 与 task 间的解耦机制，避免 竞态并允许自然丢帧（保证每帧数据完整性优于连续性）。
- 相位量的复数分量平滑：φ 直接做 EMA 会跨 ±π 边界跳变，改为对 Re,Im 分 别做 EMA 后再用 atan2f 计算平滑相位，规避了绕圈问题。
- 结构体整体赋值发布 s_result：单条 struct 赋值对协作式调度环境等效于原子 操作，无需锁。

### 3.2.5 手机端应用

手机端应用基于 Expo/React Native 框架开发，源码位于 app/ 目录。STM32 通 过 ESP8266 以 HTTP POST 上报 JSON 数据到手机端监听端口。JSON 格式：

{"f0":1000.50, "thd":0.324, "h":[U1,…,U5], "p":[φ1,…,φ5]}

手机端 App 收到后：

- 在数值卡片区展示 f0（kHz）与 THD（%）；
- 用 react-native-svg 绘制一个基频周期的重建波形，公式 y(t) = ∑5 k=1 Hk cos(2πkt+

φ

eff
k

)，其中 φ

eff
k = φk − kφ1（以 H1 相位为参考，波形在屏幕上稳定不抖）；
- 谐波表格展示 Hk/H1 归一化幅度。

### 3.3 逻辑系统框图


图 2 系统逻辑框图

### 四、测试方案与测试结果

### 4.1 测试说明

使用函数发生器的谐波发生功能产生已知失真度的正弦叠加信号，作为测量装 置的输入。理论 THDo 由发生器设定的谐波幅度按公式 (3) 计算得出。测量误差 ∆ = |THDx − THDo|。

### 4.2 测试结果

第一组低频测试（1-50 kHz 基频，30∼600 mV）：

频率 (KHz) | 峰峰值 (mV) | 二次谐波 | 三次谐波 | 四次谐波 | 五次谐波 | 失真度标称值 | 失真度测量值 | 失真度差
1 | 400 | 0 | 80 | 0 | 60 | 25% | 24.3% | 0.7%
1 | 30 | 30*0.3 | 30*0.1 | 30*0.2 | 30*0.1 | 38.73% | 38.4% | 0.33%
10 | 300 | 300*0.3 | 300*0.1 | 300*0.2 | 300*0.1 | 38.73% | 38.2% | 0.53%
30 | 450 | 0 | 450*0.2 | 450*0.133 | 450*0.1 | 26.01% | 25.7% | 0.31%

第二组高频测试（f0 = 50-100 kHz,30∼600 mV）：

频率 (KHz) | 峰峰值 (mV) | 二次谐波 | 三次谐波 | 四次谐波 | 五次谐波 | 失真度标称值 | 失真度测量值 | 失真度差
50 | 200 | 0 | 0 | 30 | 16 | 17% | 18.6% | 1.6%
60 | 450 | 450*0.3 | 450*0.1 | 450*0.2 | 450*0.1 | 38.73% | 38.2% | 0.53%
85 | 40 | 0 | 0 | 0 | 4 | 10% | 12.95% | 2.95%
100 | 40 | 0 | 0 | 0 | 4 | 10% | 49.9% | 39.9%

单片机和手机均可以实时显示失真度、谐波归一化幅度和波形图

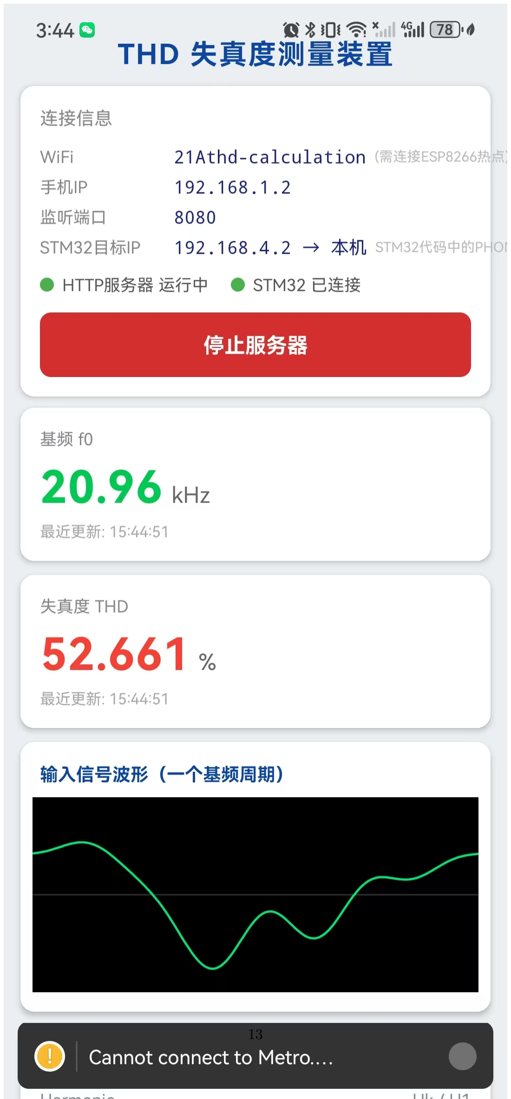
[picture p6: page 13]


图 4 单片机 lcd 显示界面

实测装置从上电到显示稳定读数的用时约为 5 秒，满足题目 10 秒内的要求。当 输入信号频率发生超过 30kHz 的变化时，计算时间会超过 10s 达到 20s

### 4.3 测试结果分析

实测结论如下：

- f0 ≤ 50 kHz：THD 测量误差稳定在 1% 以内，全面满足题目发挥部分 3% 的指 标。
- 50 kHz < f0 ≤ 85 kHz：THD 误差在 3% 以内，仍能满足题目发挥部分要求。此 区间误差略有增加的原因主要是 ADC 采样保持带宽在 500 kHz 以下的中高频段

开始下降，H4、H5 幅度略被系统性衰减。

- f0 > 85 kHz：由于 5 次谐波（> 425 kHz）已接近 Nyquist 500 kHz，ADC 采样保 持环节的非线性和抗混叠不足的双重作用下，测量精度不能保证达到题目要求， 超出本装置有效工作范围。
- 全过程用时约 5 秒

### 五、结论

本装置以 STM32F103VE 为核心构建了一套完整的信号总谐波失真度测量系统， 同时实现了 LCD 本地显示与手机端远程显示。核心贡献如下：

1. Goertzel + Hann 窗组合替代 FFT：在无 FPU 的 Cortex-M3 上实现了低开销的 高精度谐波分析，兼顾计算量与频谱精度。
2. 两级扫描 + 抛物线插值的基频估计：将 f0 定位精度控制在 ±10 Hz 量级，为后 续谐波位置准确定位打下基础。
3. 自适应采样率 auto-Fs 机制：使系统能在 1 kHz∼85 kHz 大跨度基频范围内保持 较高每帧周期数，从而降低泄漏、提高精度。为对抗混叠陷阱设计了 warmup、幅 度门槛、切档节流等保护措施，并提供全局使能开关方便实测时调整。
4. EMA 复数平滑：使显示层稳定的同时保留了对信号变化的快速追踪能力，兼顾 稳态与瞬态表现。
5. 手机端集成显示：通过 ESP8266 WiFi + 自研 React Native App 完成测量数据 的实时远端呈现，满足题目发挥部分对手机端显示的要求。

经测试，装置在 1 kHz∼85 kHz 基频、30∼600 mV 峰峰值输入下：50 kHz 以内 THD 误差 < 1%、50 kHz∼85 kHz 内误差 < 3%，从上电到显示稳定用时约 5 秒。全 面达成题目基本要求以及绝大部分发挥要求。装置结构清晰、模块化程度高、可扩展 性强，为进一步引入更高精度硬件前端或 CMSIS-DSP 定点加速留有充分空间。

附录

附录 1：核心代码片段

（1）Goertzel 复数计算（src/module/goertzel.c）

1 | goertzel_complex_t goertzel_complex(const int16_t *samples , uint32_t n,
2 | | uint32_t fs_hz, float target_hz)
3 | {
4 | const float k | = target_hz * (float)n / (float)fs_hz;
5 | const float omega = 2.0f * 3.14159265358979323846f * k / (float)n;
6 | const float cw | = cosf(omega);
7 | const float sw | = sinf(omega);
8 | const float coeff = 2.0f * cw;

9
10 | float s1 = 0.0f, s2 = 0.0f;
11 | for (uint32_t i = 0; i < n; ++i) {
12 | float s0 = coeff * s1 - s2 + (float)samples[i];
13 | s2 = s1;
14 | s1 = s0;
15 | }

16
17 | goertzel_complex_t r;
18 | r.re = s1 - s2 * cw;
19 | r.im = s2 * sw;
20 | return r;
21 | }

22
Listing 1: Goertzel 复数版本：一次扫描同时得到实部与虚部，用于计算谐波幅度和相位

（2）两级扫描 + 抛物线插值找基频（src/module/thd.c）

1 | static float estimate_f0(const int16_t *samples , uint32_t n, uint32_t fs_hz)
2 | {
3 | /* -------- 粗 扫 -------- */
4 | float coarse_stop = (float)fs_hz / 10.0f;
5 | if (coarse_stop <= s_coarse_start_hz)
6 | coarse_stop = s_coarse_start_hz + 10.0f * s_coarse_step_hz;
7 | uint32_t coarse_n = (uint32_t)((coarse_stop - s_coarse_start_hz)
8 | | / s_coarse_step_hz);
9 | if (coarse_n < 3) coarse_n = 3;

10
11 | float cp = 0, cc = 0, cn = 0;
12 | uint32_t ci = goertzel_sweep_argmax(samples , n, fs_hz,
13 | | s_coarse_start_hz , s_coarse_step_hz ,
14 | | coarse_n , &cp, &cc, &cn);
15 | float f_coarse = s_coarse_start_hz + (float)ci * s_coarse_step_hz;

16
17 | /* -------- 细 扫 -------- */
18 | float fine_start = f_coarse - s_fine_range_hz;
19 | if (fine_start < s_coarse_start_hz) fine_start = s_coarse_start_hz;
20 | uint32_t fine_n = (uint32_t)((2.0f * s_fine_range_hz) / s_fine_step_hz) + 1;

21
22 | float fp = 0, fc = 0, fn = 0;
23 | uint32_t fi = goertzel_sweep_argmax(samples , n, fs_hz,
24 | | fine_start , s_fine_step_hz ,
25 | | fine_n, &fp, &fc, &fn);
26 | float f_fine = fine_start + (float)fi * s_fine_step_hz;

27

28 | /* -------- 抛 物 线 插 值 精 调 -------- */
29 | float delta = parabolic_offset_hz(fp, fc, fn, s_fine_step_hz);
30 | return f_fine + delta;
31 | }

32
Listing 2: estimate_f0：粗扫 → 细扫 → 抛物线插值，最终精度约 ±10 Hz

（3）DMA 中断回调：去直流 + 加 Hann 窗（src/module/thd.c）

1 | static void on_adc_frame(const uint16_t *raw, uint16_t n)
2 | {
3 | if (n != THD_N_POINTS) return;
4 | if (s_frame_ready) return; | /* 上 一 帧 还 没 处 理， 丢 弃 本 帧 避 免 竞 态 */

5
6 | /* 计 算 并 减 去 DC 分 量 */
7 | int32_t sum = 0;
8 | for (uint16_t i = 0; i < n; ++i) sum += raw[i];
9 | int16_t dc = (int16_t)(sum / n);

10
11 | /* 去 直 流 + 加 Hann 窗 （Q15 定 点 乘 法： >> 15 即 除 以 32768）*/
12 | for (uint16_t i = 0; i < n; ++i) {
13 | int32_t centered = (int32_t)raw[i] - dc;
14 | s_frame[i] = (int16_t)((centered * (int32_t)s_window_q15[i]) >> 15);
15 | }
16 | s_frame_ready = true;
17 | }

18
Listing 3: ISR 中的核心预处理：均值去 DC、Q15 定点乘 Hann 窗、写入工作帧

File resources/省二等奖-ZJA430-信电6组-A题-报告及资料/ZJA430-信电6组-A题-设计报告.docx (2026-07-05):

# 信号失真度测量装置设计报告

摘要：设计并制作一个信号失真度测量装置。由函数发生器的“谐波发生”功能，产生含有不同频率谐波分量的近似放大器非线性失真信号，用MSP432E401Y的片内ADC采集测试信号。经过FFT和Geortzel算法对采集到的信号进行分析，获得基波到5次谐波分别的幅值，计算总谐波失真（THD）。设计人机交互显示界面，通过串口和ESP8266模块分别进行本地和无线数据传输，在串口屏和手机端显示归一化谐波幅值、THD、单周期波形等测试结果，并控制单片机一键启动测试。

关键词：MSP432单片机、FFT、Goertzel、总谐波失真

# 1 系统方案

## 1.1 MCU选择

#### (1) 方案一：MSP430F5529

MSP430最大主频25MHz，ADC采样频率较低，较难满足发挥部分要求的1kHz~100kHz的扩展频率测量。MSP430为16位MCU，难以满足计算信号的频域变换的要求。

#### (2) 方案二：MSP432E401Y

MSP432基于32位120MHz Arm Cortex-M4F MCU，具有FPU单元，有两个12位，最大采样率2Msps的ADC，采样和计算速度能很好地满足题目要求。同时，MSP432开发平台成熟，资料完整，便于进行设计开发。

#### (3) 方案三：EK-TM4C123GXL

EK-TM4C123GXL与MSP432的优点基本一致，具有FPU单元，有两个12位，最大采样率2Msps的ADC。最大主频略低于后者，为80MHz。

根据上述分析，最终选择MSP432开发板作为本次设计的开发平台。

## 1.2 信号处理算法选择

#### (1) 方案一：快速傅里叶变换（FFT）

FFT算法将时域信号转换到频域中，能够获得信号的频谱，便于确定基波和各谐波分量的频率并获取它们的幅值。FFT得到的频谱是离散的，由于栅栏效应的存在，要获取精确频率和幅值，需要很高的采样率以及较多的采样点数，对ADC和MCU的性能提出了较高的要求。

#### (2) 方案二：Goertzel算法

Goertzel算法是离散傅里叶变换（DFT）的简化算法，能够从给定的采样中求出某一特定频率信号的幅值，每次只计算一个频点，算法速度较快，在点数较少的采样序列上也能获得精确的结果。但Goertzel算法需要给定所求信号的频率，同时要求采样序列包含整数个周期，因此无法用于未知信号的测量。

综合两种算法的特点，本次设计采用两者的结合，先通过FFT算法获取待测信号的基波频率。在已知基波频率的前提下，再利用Goertzel算法计算基波和各谐波分量的幅值，用于计算THD。

## 1.3 测量结果显示方案

#### (1) 本地显示方案：

采用7寸串口屏进行本地测量结果显示。串口屏可预先配置好图形界面和显示格式，单片机仅需将要显示的数据打包成指令，通过串口向屏幕发送即可。串口屏还可通过串口向单片机发送指令，本次设计中采用串口屏控制测试装置一键启动测量。

#### (2) 手机显示方案：

采用ESP8266模块实现单片机和手机的通讯，手机端通过Android Studio开发数据接收程序和图形显示界面。单片机发送AT指令配置ESP8266启动TCP服务器，手机连接ESP8266的WiFi并建立TCP连接。由单片机控制ESP8266下发要显示的数据到手机。

## 1.4 波形显示方案选择

#### (1) 方案一：显示原始数据

本次设计要求显示一个周期的信号波形。由FFT算法得到信号频率后，根据采样频率可知一个周期的采样点数，因此可以在采样序列中截取一个周期的数据用于显示信号波形。

#### (2) 方案二：显示重建的波形数据

由Goertzel算法得到基波和各谐波分量的幅值数据后，根据傅里叶级数展开的原理，可由相应频率的正弦信号线性叠加，重建出原始波形。但如果无法采集到所有次数的谐波，重建出的信号和原始信号会有一定的误差。

经过实际测试，直接显示原始数据受到噪声的影响较大，尤其在输入信号幅值较小时，波形毛刺十分明显，显示很不美观。重建的波形没有噪声干扰，能更好地反映出原始信号的波形。由于输入的测试信号仅由有限次数的谐波叠加得到，用同样次数的谐波进行重建理论上不会引入额外的误差。因此，本次设计选择重建的波形数据进行显示。

# 2 测量原理和误差分析

## 2.1 误差来源分析

经过理论分析，本次设计中THD测量结果的误差主要来源于计算FFT时引入的误差。

首先，计算离散傅里叶变换会有栅栏效应，如果实际频率在频谱中相邻两频点之间，则会引入一定的误差。本次设计通过采样2048个点，尽量增加频点数量来减小该误差。

其次，采样过程对信号进行了非整数周期的截断，导致了频域上的频谱泄露，这会在测量幅值时引入误差，如果泄露的分量太强，甚至可能干扰到基波频率的测量。本次设计通过动态调整采样率，尽量使采样序列包含整数个周期，同时对采样序列加缓变的窗函数（如汉宁窗等）来减少该误差。

其他误差来源包括环境噪声、浮点运算截断误差等在本次设计的条件下较难消除，实际测试过程中对结果影响较小。

## 2.2 ADC采样率选择

决定FFT精度的主要因素有采样周期数及其是否为整数，所以不同的ADC采样频率对FFT结果准确性的影响很大。使用定时器触发MSP432E401Y内置的12bit ADC进行采样，采样率可以用如下的公式计算：

f_(sample) =1/(T_(timer))

可以通过库函数配置定时器的溢出计数值，使得一个ADC采样周期中有接近整数个周期，或者较多的周期以至于多余的部分可以忽略。ADC采样到的周期数可用如下公式计算：

k=(N_(points) ⋅f_(ADC))/(f_(signal))

# 3 软件设计

## 3.1 主程序

主程序流程图如图3.1所示。通过串口屏的按键触发测量，主要的流程包括多次采样获取基频并调整采样率，使用Goertzel算法计算二至五次谐波的幅值并计算THD，发送谐波信息至串口屏和手机进行显示。

## 3.2 关键子程序

### 3.2.1 基频提取子程序

基频提取子程序流程图如图3.2所示。ADC以最大的采样频率(1MHz)采集2048点信号样本，对离散样本进行离散快速傅里叶变换(FFT)获得信号频谱，在信号频谱中查询最大峰值，计算并记录最大峰值对应的频率，即为基频，频率分辨率=采样频率/采样点数。为了提高基频精确度，根据频率分辨率公式，减小采样频率可以提高频率分辨率，再次进行ADC采样，FFT计算，查找最大峰值，计算基频。如果在最大的采样频率(1MHz)下信号单周期采样点数小于20，则不能为了提高频率分辨率，减小采样频率，否则可能出现欠采样，导致计算的基频严重失真。

### 3.2.2 总谐波失真度测量子程序

THD测量子程序流程图如图3.3所示。由于Goertzel算法对频率较为敏感，将获得的基频对1000取整，这样在设定高次谐波频率时，频率的偏差相对较小。采样点数是否为周期的整数倍对Goertzel算法影响较大，因此只取前整数个周期进行计算；同时，其中含有的周期数不宜过大，否则采样误差会对计算精度造成较大影响，于是设置周期数上限为10个。为了获取更加稳定和准确的THD值，连续多次进行ADC采样和上述计算，去掉最大值和最小值后取平均值作为本次THD测量结果。

### 3.2.3 TCP传输子程序

TCP传输子程序流程图如图3.4所示。由于传输数据格式固定且数量不大，所以直接通过TCP传输格式化文本，在简化了设计复杂度的同时加快了传输速率。通过串口发送AT指令到ESP8266模块，配置TCP服务和连接客户端，如有设备接入，则通过socket将归一化谐波幅度、基频、THD等信息发送到客户端进行显示。

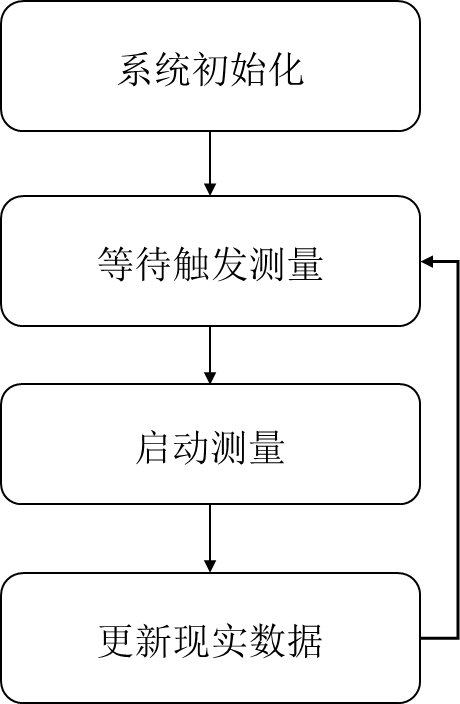
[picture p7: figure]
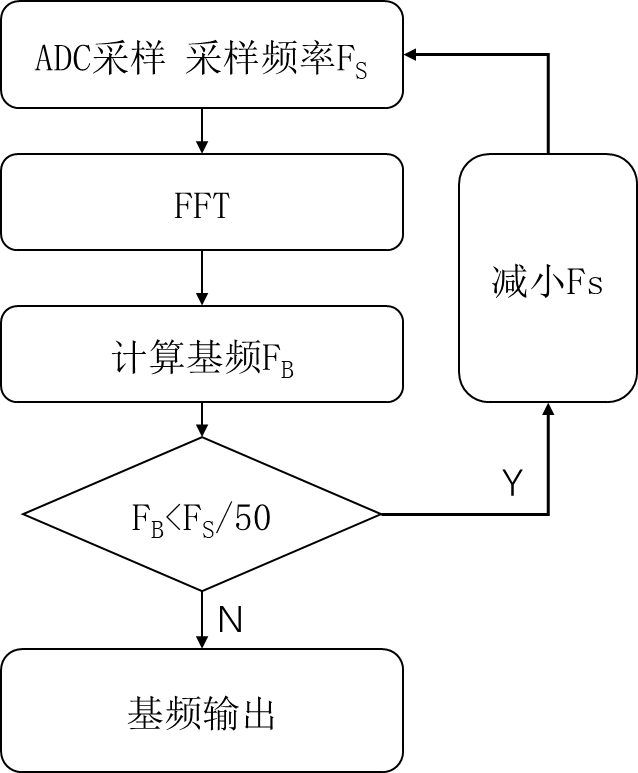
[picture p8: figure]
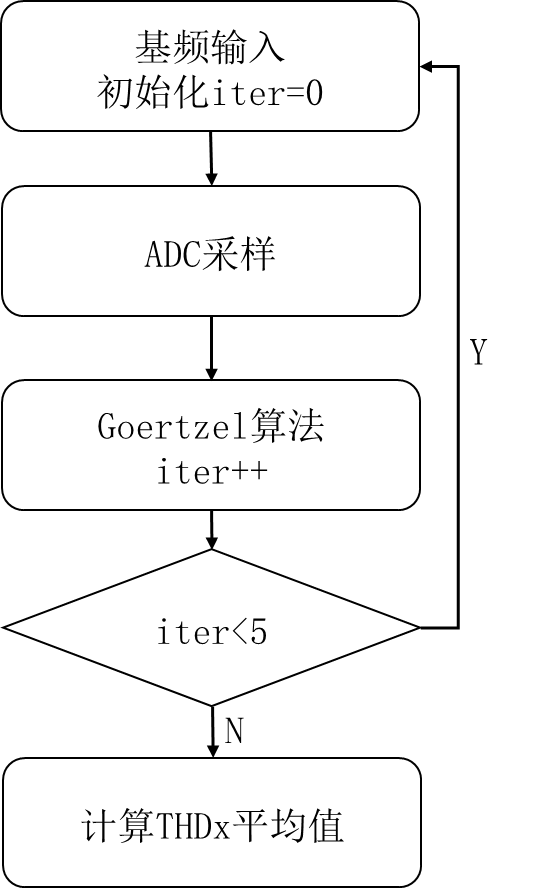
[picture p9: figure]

图3.1 主程序 | 图3.2 基频提取 | 图3.3 总谐波失真

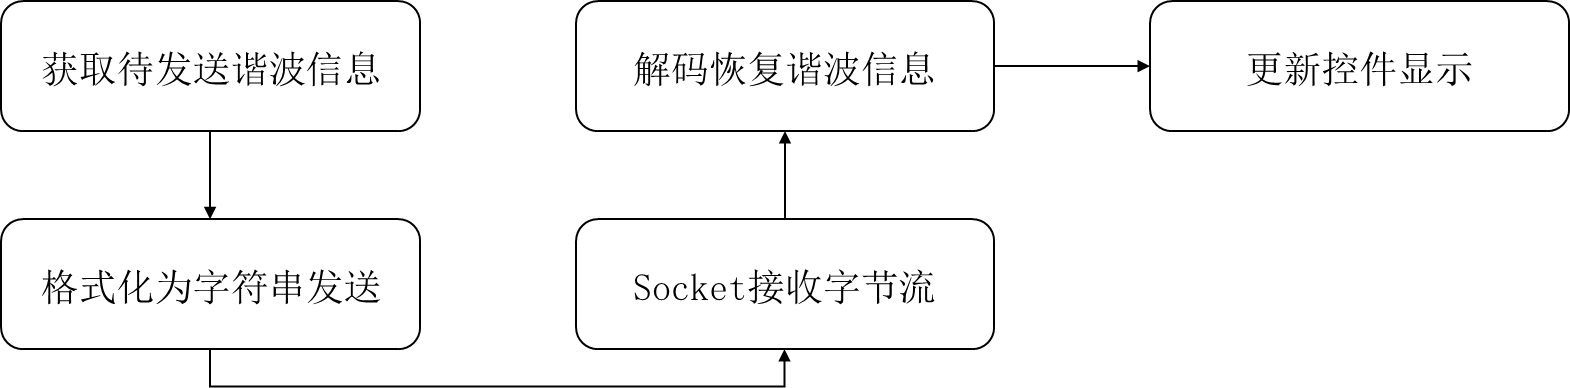
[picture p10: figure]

图3.4 TCP传输

# 4 系统测试

## 4.1 测试条件

直流稳压电源JC3003A-3，示波器GDS-1152A-U，信号发生器DG-4202，台式万用表VC8145。

## 4.2 测试方案

系统测试的理论要求，测试项目完整、测试覆盖率100%，现实无法实现100%的覆盖率，一般地，需要在测试效率和覆盖率之间取舍，为了系统测试完整性，测试边界矢量是必须的。测试矢量={测试变量1，测试变量2，……，测试变量n }。为了达到测试的完整性，本项目测试方案选择测试频率边界、电压边界，在测试边界的基础上尽可能使用典型的非边界测试矢量。

## 4.3 测试数据

### 4.3.1 基本要求测试

表4.1 基本要求测试结果

基波频率f=1kHz
Vpp | 300mV | 450mV | 600mV
THDO/% | 40%
THDX/% | 40.19 | 40.09 | 40.13
Δ /% | 0.19 | 0.09 | 0.13
Vpp | 300mV
THDO/% | 5 | 20 | 50
THDX/% | 5.05 | 20.07 | 50.09
Δ /% | 0.05 | 0.07 | 0.09

### 4.3.2 发挥部分测试

表4.2 发挥部分要求测试结果（1）

基波频率f=1kHz
Vpp | 30mV | 100mV | 200mV
THDO/% | 50
THDX/% | 50.33 | 49.85 | 50.29
Δ /% | 0.33 | 0.15 | 0.29
Vpp | 100mV
THDO/% | 5 | 20 | 40
THDX/% | 5.01 | 20.03 | 39.99
Δ /% | 0.01 | 0.03 | 0.01

表4.3 发挥部分要求测试结果（2）

Vpp=300mV
基波频率f/kHz | 10 | 30 | 50 | 70 | 80 | 100
THDo/% | 35
THDx/% | 34.57 | 35.5 | 35.41 | 35.53 | 30.09 | 23.15
Δ /% | 0.43 | 0.5 | 0.41 | 0.53 | 4.91 | 11.85
f固定 | 5kHz
THDO/% | 5 | | 30 | | 50
THDx/% | 5.16 | | 30.20 | | 50.12
Δ /% | 0.16 | | 0.20 | | 0.12

## 4.4 结果分析

经测试，在基础要求下，本次设计的失真度测试装置能够满足所有设计要求，失真度测试结果精确。

在发挥部分中，对于幅值更小的测试信号失真度测试装置也能够准确测量失真度，但对于基波频率更高的测试信号无法准确测量，当基波频率大于80KHz后，测量结果不再满足要求。

所有测试经过计时，均能够在10s以内显示测量结果。

# 5 结论

本次设计最终实现了信号失真度测量装置，满足所有基本要求和部分发挥要求。

本次设计还可以对于人机交互、通信鲁棒性等进行进一步优化。

# 6 参考文献

[1] 童诗白, 华成英: 模拟电子技术基础[M]. 北京: 高等教育出版社, 2015.
[2] 仇佩亮, 陈惠芳, 谢磊. 数字通信基础[M]. 电子工业出版社, 2007.

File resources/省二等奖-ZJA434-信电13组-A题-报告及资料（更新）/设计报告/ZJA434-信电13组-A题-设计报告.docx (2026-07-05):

信号失真度测量装置（A 题）

摘要：

本系统以TI公司的MSP-EXP432E开发板作为计算核心，配合OP2727，AD620等搭建的滤波电路和放大电路，并用手机app和广州大彩7寸串口屏辅助显示，实现信号失真度测量装置的制作。我们采用SDG6052X-E任意波形发生器作为测试激励，通过滤波电路分离信号中的交流和直流分量，经过适当放大后分别送入单片机的两个ADC，进行fft操作，最终将信号失真度、各谐波分量比值、信号发生波形等数据发送给7寸屏和手机蓝牙。

关键词：MSP432开发板，信号失真度，7寸串口屏，蓝牙通讯。

一、方案对比与论证

1.与手机通讯方案

方案一：使用esp8266WIFI模块

方案二：使用HC-05蓝牙模块

两者的工作量和稳定性大致相同，但是考虑到app inventor制作软件与蓝牙的适配性，为便于开发选择方案二。

2.开发环境选择

方案一：使用TI公司的MSP430-F5529开发板

方案二：使用TI公司的MSP432-E401Y开发板

430板带有1个12位ADC，转换率为200ksps；432板带有两个ADC，转换率为2Msps。因本题对ADC性能要求较高，故选择方案二

3数据采样与储存方案

方案一：使用定时器触发+DMA搬运

方案二：使用CPU轮询采样

考虑到靠cpu轮询采样，一方面速度不稳定，另一方面实测中速度也达不到1Msps，所以选择方案二。

4.分离交流量方案

方案一：使用无源的PI型高通滤波器

方案二：使用有源的SK-II型高通滤波器

考虑到分离交流量的要求和条件较为简单，所以使用更为简单可靠的无源型滤波器。

二、理论分析与计算

1.失真度分析与计算

本设计中信号失真度测量采用近似方式，测量和分析输入信号5次谐波成分。（1）定义失真度的标称值为：

THD_o =(√(U_(o2) ^2 +U_(o3) ^2 +U_04 ^2 +U_(o5) ^2))/(U_(o1))×100%

（2）定义失真度测量误差为测量值与标称值的绝对误差：

δ=|THD_X -THD_O |

（3）定义基波与谐波的归一化幅值依次分别为：

1、(U_(m2))/(U_(m1))、(U_(m3))/(U_(m1))、(U_(m4))/(U_(m1))、(U_(m5))/(U_(m1))

2.滤波电路分析与参数计算

考虑到波形发生器传入的信号可能存在直流量，如果将直流量也经过放大电路容易超过单片机接受的阈值电压3V，所以将直流量分离单独送入单片机，将交流量送入放大电路。其中，交流/直流分离电路选用PI型滤波器。

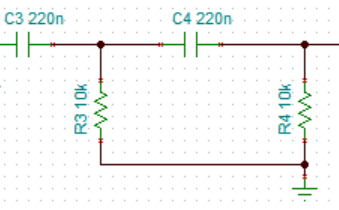
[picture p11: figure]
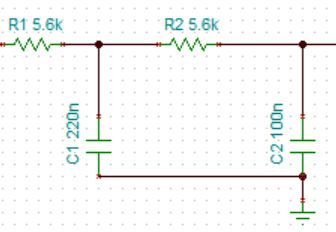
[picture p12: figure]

图表 1通交流电路

图表 2通直流电路

对于上图中的二阶PI型低通RC滤波电路，截止频率计算公式为

f_0 =1/(2π*2.67*√(R_1 R_2 C_1 C_2))

设置f0=75HZ，取R1=R2=5.6K，取C1=220nF，C2=100nF。

对于上图中的二阶PI型低通RC滤波电路，截止频率计算公式为

f_0 =2.67/(2π*√(R_1 R_2 C_1 C_2))

设置f0=200HZ，取R1=R2=10K，取C1=C2=220nF。

3.放大电路分析与参数计算

放大电路采用单级的AD620仪表放大器，其具有失调漂移低、噪声低的特点。考虑到输入交流信号峰峰值为30mv-600mv，而单片机ADC接受电压范围为0-3v，所以设计放大倍数为4-5倍。根据AD620的增益公式：

Gain=(49.8KΩ)/(R_G)+1

选择标称15K电阻，最终确定放大倍数为4.3倍，并通过REF端口加上1.5V的直流偏置电压。

4. Goertzel算法

用于求单点的FFT变换，从给定的采样中求特定频率的幅值，通过迭代的方法实现。

三、电路与程序设计

1.方案总体设计

（1）系统总框图：

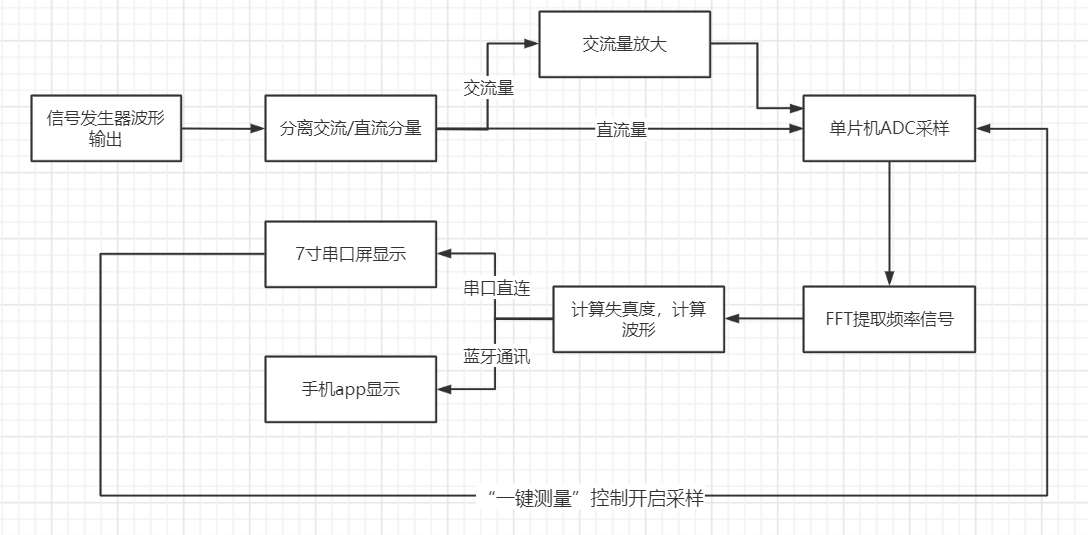
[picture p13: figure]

（2）具体电路图

①滤波电路。

为减小对后级pi型滤波器的干扰，信号源输入先通过2个buf634缓冲器隔离。通过滤波器后，再经过两个OPA2727构成的缓冲器。

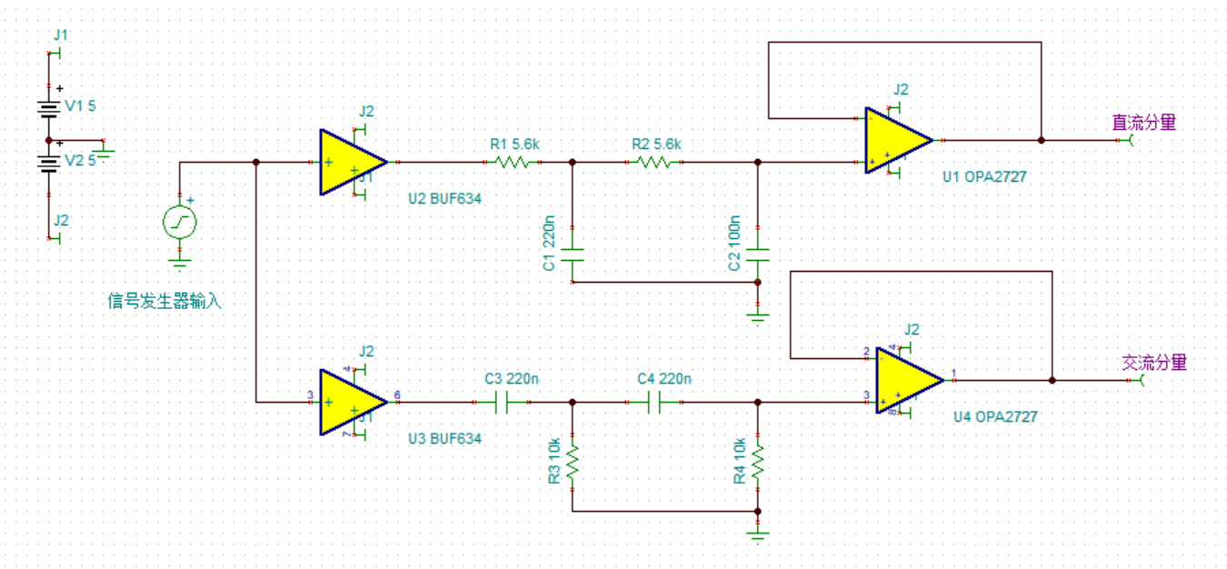
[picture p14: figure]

②放大电路

将分离出的交流量送入放大电路，放大倍数4.3，直流偏置电压1.5V。

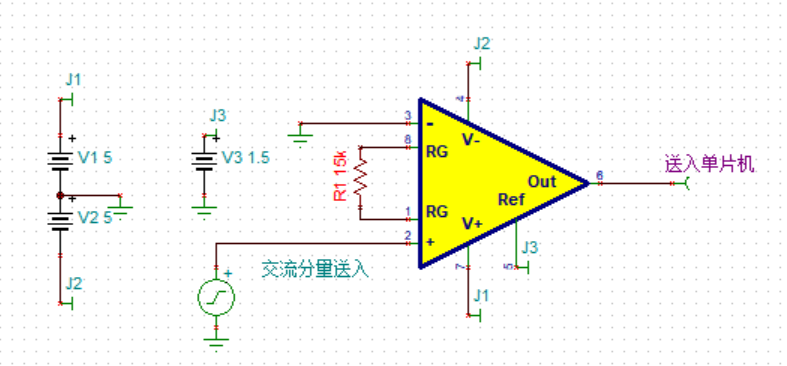
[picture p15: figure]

2.单片机部分设计

使用TI公司的MSP432E401Y作为主控制器，使用片内ADC进行信号采集。实现了高速ADC数据采集存储、FFT变换寻找主频与计算THD并输出。
（1）ADC数据采样与存储
为了完成采集100kHz信号的5次谐波采样，采样频率至少为1MHz。使用定时器触发采样+DMA搬运数据的方案，经过测试可以达到1Msps的采样。
（2）FFT变换与频谱处理
使用FFT算法获取输入信号的频谱，寻找频谱幅度最大点并取其谐波的幅度计算THD。事实上，FFT的频域精度受采样点数限制，而由于时间和速度要求，点数有限。通过加窗可以一定程度上改善这一问题，但对于偏离采样点较远的频率点，其幅度值仍不精确。最终采用单点FFT算法之一的Goertzel算法，提高频域精度。对于低频信号，如1kHz，由于离0点太近会严重被直流分量影响。首先，通过求平均电压进行直流去除，效果仍然不理想。最终在测量低频信号时调低ADC采样频率，拉大0点与低频点在频谱上的距离以提高精度。
（3）THD计算
通过FFT获取并算出主频后，使用Goertzel算法输入频率求出各次谐波幅值，按公式计算THD。
（4）波形重建
获取到各次谐波幅值后，通过正弦信号叠加重建出收到的信号。由于性能限制，只重建到5次谐波。

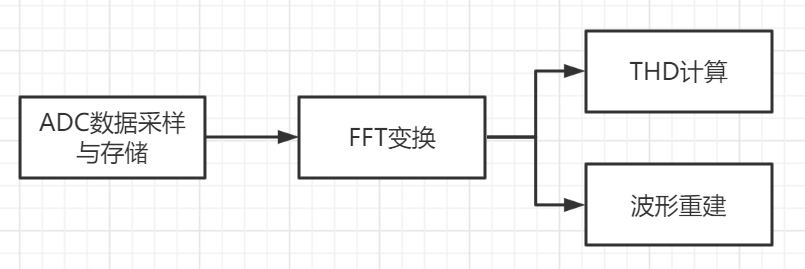
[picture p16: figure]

3.手机app设计和7寸串口屏设计

测量装置使用触摸屏控制和显示结果。按下测量按键后，MCU通过串口收到信号开始采集，采集完毕后将数据通过串口重新传送给屏幕，显示峰峰值、频率、THD，各次谐波幅值，重建波形图像等。并通过蓝牙模块发送到手机端APP，APP同样可以显示THD，各次谐波幅值、波形图像等。

四、测试记录与分析

1.失真度测试及谐波分量测试

组号 | 输入输出 | 频率(KHz) | 峰峰值 | 二次谐波 | 三次谐波 | 四次谐波 | 五次谐波 | 失真度(%) | 失真度差
1 | 输入 | 1 | 30 | 0 | 0 | 0 | 0 | 0 | 0
| 输出 | 1 | 31 | 0 | 0 | 0 | 0 | 0
2 | 输入 | 1 | 30 | 0.1 | 0.1 | 0.1 | 0.1 | 20 | 0.34
| 输出 | 1 | 31 | 0.101 | 0.101 | 0.101 | 0.102 | 20.34
3 | 输入 | 1 | 30 | 0.3 | 0.1 | 0.2 | 0.1 | 38.73 | 1.15
| 输出 | 1 | 36 | 0.311 | 0.101 | 0.203 | 0.102 | 39.88
4 | 输入 | 1 | 300 | 0.3 | 0.1 | 0.2 | 0.1 | 38.73 | 1.42
| 输出 | 1 | 350 | 0.31 | 0.102 | 0.208 | 0.103 | 40.15
5 | 输入 | 1 | 600 | 0 | 0 | 0 | 0 | 0 | 0
| 输出 | 1 | 601 | 0 | 0 | 0 | 0 | 0
6 | 输入 | 1 | 600 | 0.3 | 0.1 | 0.2 | 0.1 | 38.73 | 1.56
| 输出 | 1 | 698 | 0.311 | 0.103 | 0.208 | 0.104 | 40.29
7 | 输入 | 10 | 300 | 0.3 | 0.1 | 0.2 | 0.1 | 38.73 | 0.56
| 输出 | 9.9 | 337 | 0.305 | 0.1 | 0.202 | 0.1 | 39.29
8 | 输入 | 30 | 50 | 0 | 0 | 0 | 0 | 0 | 0
| 输出 | 29.9 | 52 | 0 | 0 | 0 | 0 | 0
9 | 输入 | 50 | 300 | 0.3 | 0.1 | 0.2 | 0.1 | 38.73 | 0.95
| 输出 | 49.9 | 335 | 0.306 | 0.101 | 0.207 | 0.103 | 39.68
10 | 输入 | 60 | 450 | 0.3 | 0.1 | 0.2 | 0.1 | 38.73 | 1.4
| 输出 | 59.9 | 512 | 0.307 | 0.103 | 0.211 | 0.106 | 40.13
11 | 输入 | 75 | 450 | 0 | 0.2 | 0.133 | 0.1 | 26.01 | 1.69
| 输出 | 74.9 | 452 | 0 | 0.21 | 0.143 | 0.109 | 27.7
12 | 输入 | 100 | 300 | 0.3 | 0.1 | 0.2 | 0.1 | 38.73 | 2.25
| 输出 | 99.9 | 350 | 0.311 | 0.106 | 0.221 | 0.097 | 40.98
13 | 输入 | 100 | 30 | 0.3 | 0.1 | 0.2 | 0.1 | 38.73 | -0.12
| 输出 | 99.8 | 36 | 0.292 | 0.101 | 0.202 | 0.098 | 38.61
14 | 输入 | 100 | 600 | 0.3 | 0.1 | 0.2 | 0.1 | 38.73 | 1.81
| 输出 | 99.8 | 707 | 0.307 | 0.102 | 0.214 | 0.109 | 40.54

备注：

（1）输入的峰峰值为基波的峰峰值，输出的峰峰值为加入谐波的整体峰峰值。

（2）输入的失真度为标称失真度，输出的失真度为测量失真度。

（3）峰峰值单位为mV。

2.显示测试

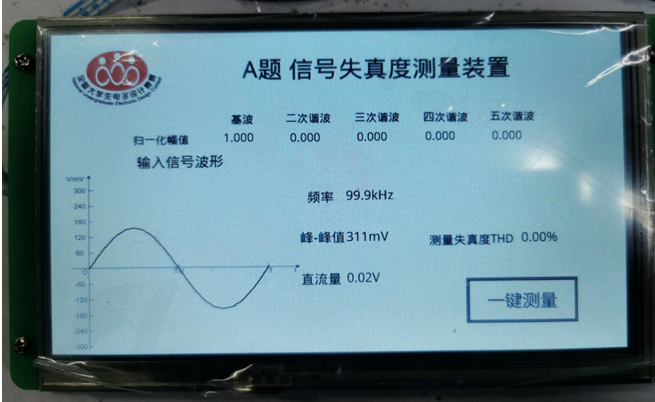
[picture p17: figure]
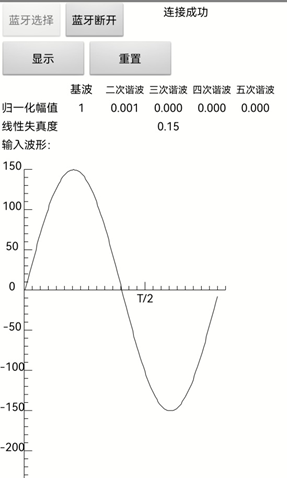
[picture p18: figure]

五、结论

本小组搭建了信号失真度测量装置，可以实现30-600mv峰峰值、1K-100K频率、带有一定直流偏置电压信号的失真度测量，可以显示包括失真度、各次谐波归一化幅值，原信号的波形、幅值、频率。实验结果14组数据，失真度测量误差均实现题目的基本要求和进阶要求，并且可通过7寸串口屏和手机app显示。

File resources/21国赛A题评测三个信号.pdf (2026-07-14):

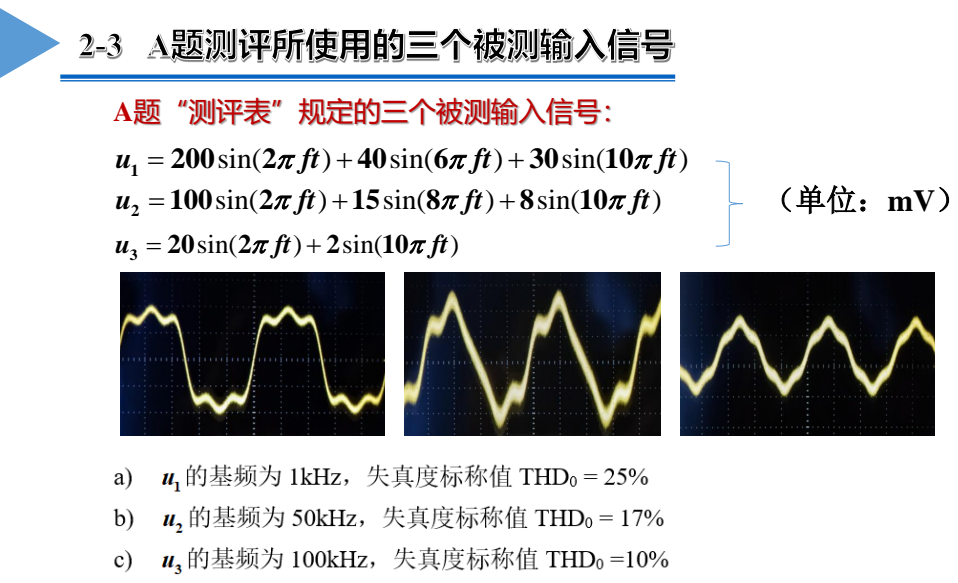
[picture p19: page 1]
10 sin(; sin(

A题“测评表”规定的三个被测输入信号：

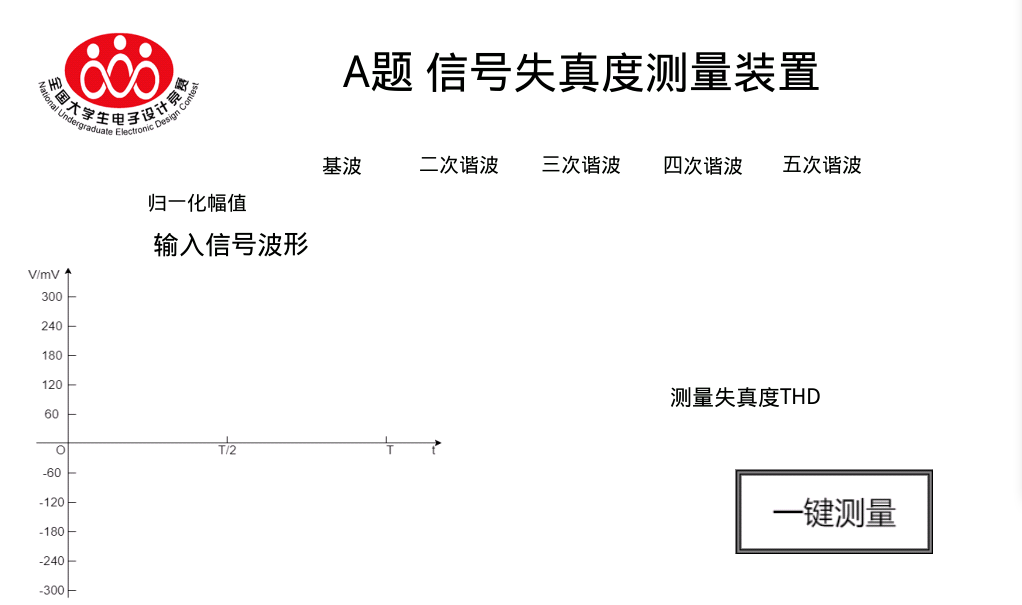
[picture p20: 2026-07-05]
resources/省二等奖-ZJA434-信电13组-A题-报告及资料（更新）/code/Wave_Display_Screen/images/background1.png

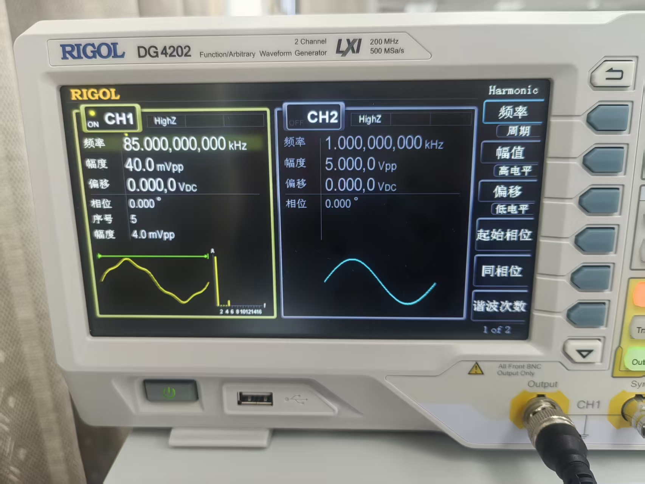
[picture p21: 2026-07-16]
resources/figure/85k测量/信号发生器.jpg

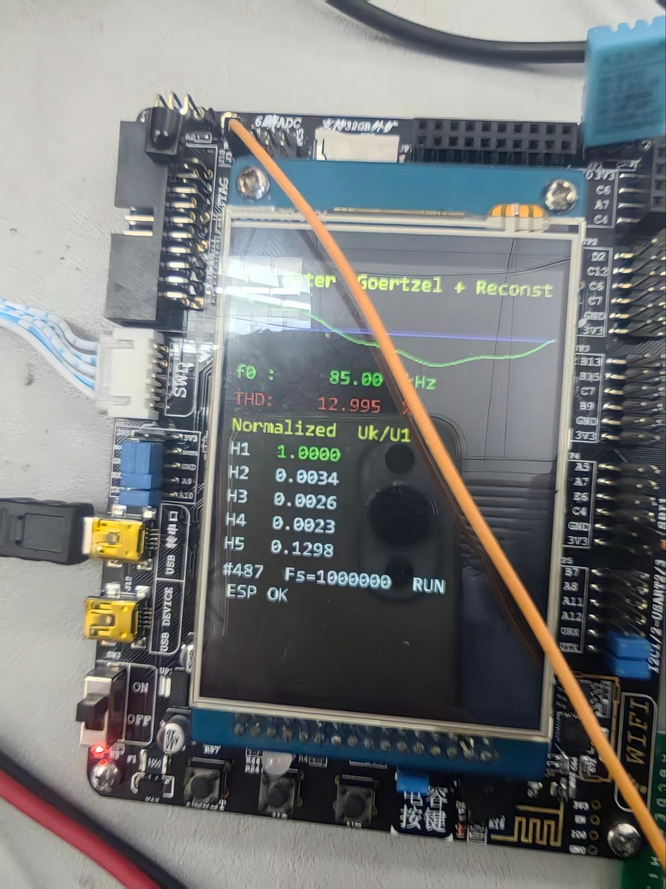
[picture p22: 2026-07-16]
resources/figure/85k测量/单片机.jpg

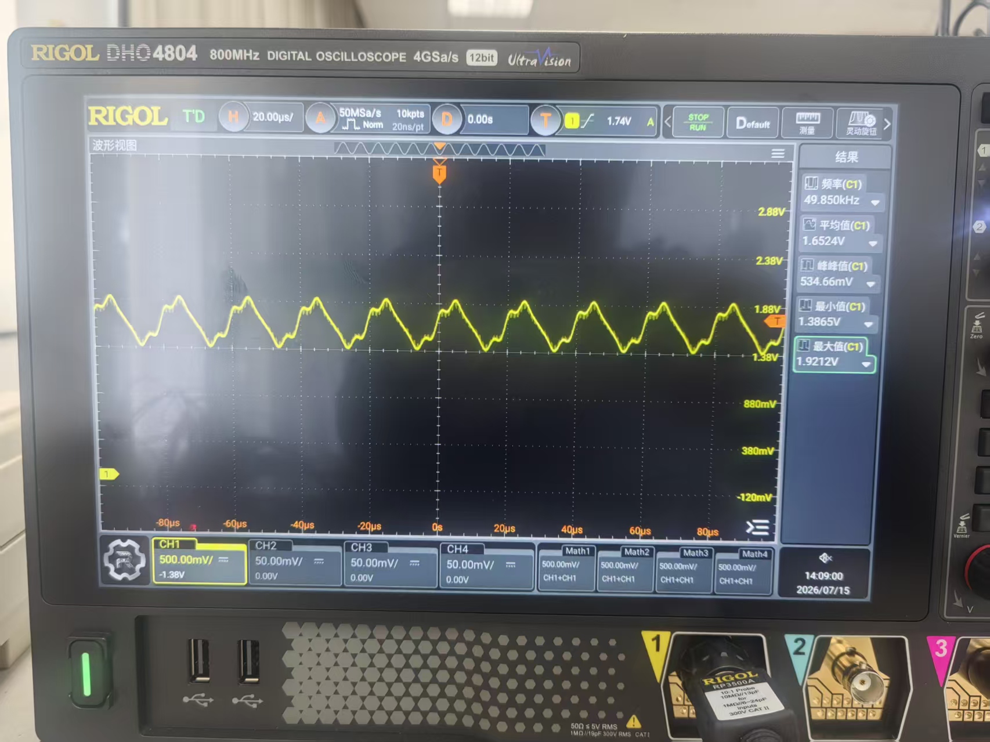
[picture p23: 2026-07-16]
resources/figure/50k测量/示波器.jpg

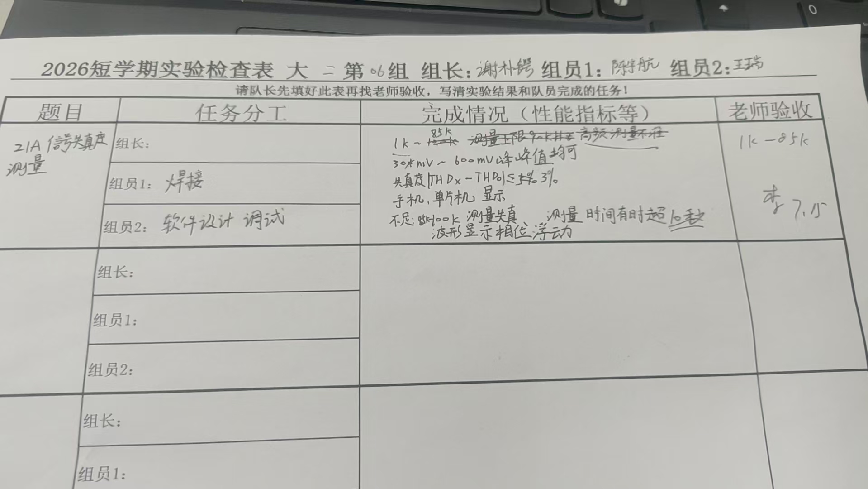
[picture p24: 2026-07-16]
resources/figure/验收表.jpg

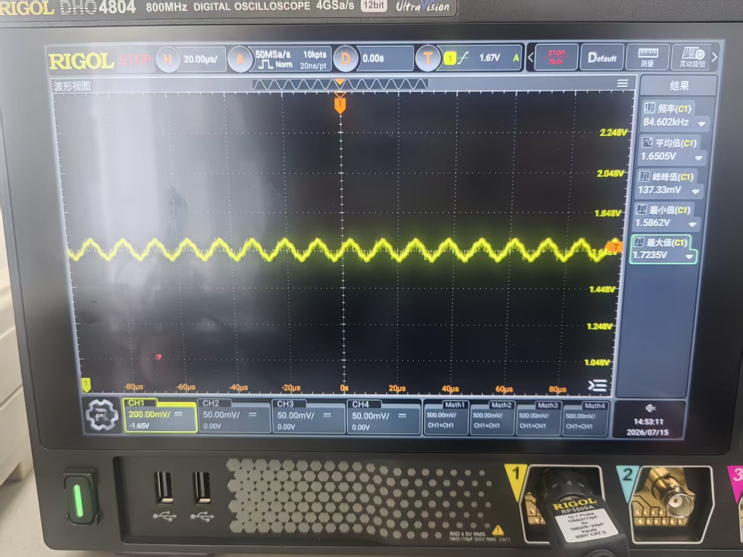
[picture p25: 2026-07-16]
resources/figure/85k测量/示波器.jpg

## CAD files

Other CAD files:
resources/省二等奖-ZJA430-信电6组-A题-报告及资料/ZJA430-信电6组-代码/THD-detect/Debug/adc/adc.obj
resources/省二等奖-ZJA430-信电6组-A题-报告及资料/ZJA430-信电6组-代码/THD-detect/Debug/ccs/startup_msp432e401y_ccs.obj
resources/省二等奖-ZJA430-信电6组-A题-报告及资料/ZJA430-信电6组-代码/THD-detect/Debug/esp8266/esp8266.obj
resources/省二等奖-ZJA430-信电6组-A题-报告及资料/ZJA430-信电6组-代码/THD-detect/Debug/fft/arm_fft.obj
resources/省二等奖-ZJA430-信电6组-A题-报告及资料/ZJA430-信电6组-代码/THD-detect/Debug/goertzel/goertzel.obj
resources/省二等奖-ZJA430-信电6组-A题-报告及资料/ZJA430-信电6组-代码/THD-detect/Debug/printf/printf.obj
resources/省二等奖-ZJA430-信电6组-A题-报告及资料/ZJA430-信电6组-代码/THD-detect/Debug/sdwa/bsp_sdwa.obj
resources/省二等奖-ZJA434-信电13组-A题-报告及资料（更新）/code/empty_MSP_EXP432E401Y_nortos_ccs/Debug/ccs/startup_msp432e401y_ccs.obj
resources/省二等奖-ZJA434-信电13组-A题-报告及资料（更新）/code/empty_MSP_EXP432E401Y_nortos_ccs/Debug/Goertzel/Goertzel.obj
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

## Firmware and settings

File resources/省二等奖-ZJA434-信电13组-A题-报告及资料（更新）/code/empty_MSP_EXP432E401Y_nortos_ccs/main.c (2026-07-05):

/* --COPYRIGHT--,BSD
 * Copyright (c) 2017, Texas Instruments Incorporated
 * All rights reserved.
 *
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
 * *  Redistributions of source code must retain the above copyright
 *    notice, this list of conditions and the following disclaimer.
 *
 * *  Redistributions in binary form must reproduce the above copyright
 *    notice, this list of conditions and the following disclaimer in the
 *    documentation and/or other materials provided with the distribution.
 *
 * *  Neither the name of Texas Instruments Incorporated nor the names of
 *    its contributors may be used to endorse or promote products derived
 *    from this software without specific prior written permission.
 *
 * THIS SOFTWARE IS PROVIDED BY THE COPYRIGHT HOLDERS AND CONTRIBUTORS "AS IS"
 * AND ANY EXPRESS OR IMPLIED WARRANTIES, INCLUDING, BUT NOT LIMITED TO,
 * THE IMPLIED WARRANTIES OF MERCHANTABILITY AND FITNESS FOR A PARTICULAR
 * PURPOSE ARE DISCLAIMED. IN NO EVENT SHALL THE COPYRIGHT OWNER OR
 * CONTRIBUTORS BE LIABLE FOR ANY DIRECT, INDIRECT, INCIDENTAL, SPECIAL,
 * EXEMPLARY, OR CONSEQUENTIAL DAMAGES (INCLUDING, BUT NOT LIMITED TO,
 * PROCUREMENT OF SUBSTITUTE GOODS OR SERVICES; LOSS OF USE, DATA, OR PROFITS;
 * OR BUSINESS INTERRUPTION) HOWEVER CAUSED AND ON ANY THEORY OF LIABILITY,
 * WHETHER IN CONTRACT, STRICT LIABILITY, OR TORT (INCLUDING NEGLIGENCE OR
 * OTHERWISE) ARISING IN ANY WAY OUT OF THE USE OF THIS SOFTWARE,
 * EVEN IF ADVISED OF THE POSSIBILITY OF SUCH DAMAGE.
 * --/COPYRIGHT--*/
/******************************************************************************
 * MSP432E4 Empty Project
 *
 * Description: An empty project that uses DriverLib
 *
 *                MSP432E401Y
 *             ------------------
 *         /|\|                  |
 *          | |                  |
 *          --|RST               |
 *            |                  |
 *            |                  |
 *            |                  |
 *            |                  |
 *            |                  |
 * Author: 
*******************************************************************************/
/* DriverLib Includes */
#include <ti/devices/msp432e4/driverlib/driverlib.h>

/* Standard Includes */
#include <stdint.h>
#include <stdbool.h>
#include <math.h>
#include "./window/inc/window.h"
#include "./Goertzel/Goertzel.h"
/* Display Include via console */
#include "uartstdio.h"

/* The control table used by the uDMA controller.  This table must be aligned
 * to a 1024 byte boundary. */
#if defined(__ICCARM__)
#pragma data_alignment=1024
uint8_t pui8ControlTable[1024];
#elif defined(__TI_ARM__)
#pragma DATA_ALIGN(pui8ControlTable, 1024)
uint8_t pui8ControlTable[1024];
#else
uint8_t pui8ControlTable[1024] __attribute__ ((aligned(1024)));
#endif

uint16_t ADCBuffer[1024];

#define MAXSIZE 64
#define AMP 4.25

int32_t *getADCBuffer(int32_t index);
double *getVRBuffer(int32_t index);
double *getVIBuffer(int32_t index);
double *getFFTRBuffer(int32_t index);
double *getFFTIBuffer(int32_t index);
void kfft(int32_t n, int32_t k);




double sig_out[128];
double sig_max = -4096;
double sig_min = 4096;
double sig_pp = 0;

int32_t ADCBuffer0[MAXSIZE];
int32_t ADCBuffer1[MAXSIZE];
int32_t ADCBuffer2[MAXSIZE];
int32_t ADCBuffer3[MAXSIZE];
int32_t ADCBuffer4[MAXSIZE];
int32_t ADCBuffer5[MAXSIZE];
int32_t ADCBuffer6[MAXSIZE];
int32_t ADCBuffer7[MAXSIZE];
int32_t ADCBuffer8[MAXSIZE];
int32_t ADCBuffer9[MAXSIZE];
int32_t ADCBuffera[MAXSIZE];
int32_t ADCBufferb[MAXSIZE];
int32_t ADCBufferc[MAXSIZE];
int32_t ADCBufferd[MAXSIZE];
int32_t ADCBuffere[MAXSIZE];
int32_t ADCBufferf[MAXSIZE];

double VRBuffer0[MAXSIZE];
double VRBuffer1[MAXSIZE];
double VRBuffer2[MAXSIZE];
double VRBuffer3[MAXSIZE];
double VRBuffer4[MAXSIZE];
double VRBuffer5[MAXSIZE];
double VRBuffer6[MAXSIZE];
double VRBuffer7[MAXSIZE];
double VRBuffer8[MAXSIZE];
double VRBuffer9[MAXSIZE];
double VRBuffera[MAXSIZE];
double VRBufferb[MAXSIZE];
double VRBufferc[MAXSIZE];
double VRBufferd[MAXSIZE];
double VRBuffere[MAXSIZE];
double VRBufferf[MAXSIZE];

double VIBuffer0[MAXSIZE];
double VIBuffer1[MAXSIZE];
double VIBuffer2[MAXSIZE];
double VIBuffer3[MAXSIZE];
double VIBuffer4[MAXSIZE];
double VIBuffer5[MAXSIZE];
double VIBuffer6[MAXSIZE];
double VIBuffer7[MAXSIZE];
double VIBuffer8[MAXSIZE];
double VIBuffer9[MAXSIZE];
double VIBuffera[MAXSIZE];
double VIBufferb[MAXSIZE];
double VIBufferc[MAXSIZE];
double VIBufferd[MAXSIZE];
double VIBuffere[MAXSIZE];
double VIBufferf[MAXSIZE];

double FFTRBuffer0[MAXSIZE];
double FFTRBuffer1[MAXSIZE];
double FFTRBuffer2[MAXSIZE];
double FFTRBuffer3[MAXSIZE];
double FFTRBuffer4[MAXSIZE];
double FFTRBuffer5[MAXSIZE];
double FFTRBuffer6[MAXSIZE];
double FFTRBuffer7[MAXSIZE];
double FFTRBuffer8[MAXSIZE];
double FFTRBuffer9[MAXSIZE];
double FFTRBuffera[MAXSIZE];
double FFTRBufferb[MAXSIZE];
double FFTRBufferc[MAXSIZE];
double FFTRBufferd[MAXSIZE];
double FFTRBuffere[MAXSIZE];
double FFTRBufferf[MAXSIZE];

double FFTIBuffer0[MAXSIZE];
double FFTIBuffer1[MAXSIZE];
double FFTIBuffer2[MAXSIZE];
double FFTIBuffer3[MAXSIZE];
double FFTIBuffer4[MAXSIZE];
double FFTIBuffer5[MAXSIZE];
double FFTIBuffer6[MAXSIZE];
double FFTIBuffer7[MAXSIZE];
double FFTIBuffer8[MAXSIZE];
double FFTIBuffer9[MAXSIZE];
double FFTIBuffera[MAXSIZE];
double FFTIBufferb[MAXSIZE];
double FFTIBufferc[MAXSIZE];
double FFTIBufferd[MAXSIZE];
double FFTIBuffere[MAXSIZE];
double FFTIBufferf[MAXSIZE];

uint32_t getDCVoltage;

double v_ave = 0;
double vmin = 3.3;
double vmax = 0;
double vpp = 0;
uint32_t vmax_i = 0;

double magmax = 0;
uint32_t magmax_i = 0;

double f_test[21];
double mag_test[21];
double mag_test_max;
uint32_t mag_test_i;

double f_in;
double THD;
double f_out;
double THD_out;
double mag_out[5];

double v_dc = 0;

double vv_temp = 5;

double mag_amp = 0;

volatile uint16_t transfer_flag = 0;
uint16_t transfer_count = 0;

uint16_t circle_count = 0;
uint8_t uart_temp;

double sample_rate = 1000000.0;

int32_t *getADCBuffer(int32_t index)
{
    uint32_t temp;
    temp = index / MAXSIZE;
    switch(temp){
        case 0:
            return &ADCBuffer0[index];
        case 1:
            return &ADCBuffer1[index - temp * MAXSIZE];
        case 2:
            return &ADCBuffer2[index - temp * MAXSIZE];
        case 3:
            return &ADCBuffer3[index - temp * MAXSIZE];
        case 4:
            return &ADCBuffer4[index - temp * MAXSIZE];
        case 5:
            return &ADCBuffer5[index - temp * MAXSIZE];
        case 6:
            return &ADCBuffer6[index - temp * MAXSIZE];
        case 7:
            return &ADCBuffer7[index - temp * MAXSIZE];
        case 8:
            return &ADCBuffer8[index - temp * MAXSIZE];
        case 9:
            return &ADCBuffer9[index - temp * MAXSIZE];
        case 10:
            return &ADCBuffera[index - temp * MAXSIZE];
        case 11:
            return &ADCBufferb[index - temp * MAXSIZE];
        case 12:
            return &ADCBufferc[index - temp * MAXSIZE];
        case 13:
            return &ADCBufferd[index - temp * MAXSIZE];
        case 14:
            return &ADCBuffere[index - temp * MAXSIZE];
        case 15:
            return &ADCBufferf[index - temp * MAXSIZE];
    }
    return &ADCBuffer0[0];
}

double *getVRBuffer(int32_t index)
{
    uint32_t temp;
    temp = index / MAXSIZE;
    switch(temp){
        case 0:
            return &VRBuffer0[index];
        case 1:
            return &VRBuffer1[index - temp * MAXSIZE];
        case 2:
            return &VRBuffer2[index - temp * MAXSIZE];
        case 3:
            return &VRBuffer3[index - temp * MAXSIZE];
        case 4:
            return &VRBuffer4[index - temp * MAXSIZE];
        case 5:
            return &VRBuffer5[index - temp * MAXSIZE];
        case 6:
            return &VRBuffer6[index - temp * MAXSIZE];
        case 7:
            return &VRBuffer7[index - temp * MAXSIZE];
        case 8:
            return &VRBuffer8[index - temp * MAXSIZE];
        case 9:
            return &VRBuffer9[index - temp * MAXSIZE];
        case 10:
            return &VRBuffera[index - temp * MAXSIZE];
        case 11:
            return &VRBufferb[index - temp * MAXSIZE];
        case 12:
            return &VRBufferc[index - temp * MAXSIZE];
        case 13:
            return &VRBufferd[index - temp * MAXSIZE];
        case 14:
            return &VRBuffere[index - temp * MAXSIZE];
        case 15:
            return &VRBufferf[index - temp * MAXSIZE];
    }
    return &VRBuffer0[0];
}

double *getVIBuffer(int32_t index)
{
    uint32_t temp;
    temp = index / MAXSIZE;
    switch(temp){
        case 0:
            return &VIBuffer0[index];
        case 1:
            return &VIBuffer1[index - temp * MAXSIZE];
        case 2:
            return &VIBuffer2[index - temp * MAXSIZE];
        case 3:
            return &VIBuffer3[index - temp * MAXSIZE];
        case 4:
            return &VIBuffer4[index - temp * MAXSIZE];
        case 5:
            return &VIBuffer5[index - temp * MAXSIZE];
        case 6:
            return &VIBuffer6[index - temp * MAXSIZE];
        case 7:
            return &VIBuffer7[index - temp * MAXSIZE];
        case 8:
            return &VIBuffer8[index - temp * MAXSIZE];
        case 9:
            return &VIBuffer9[index - temp * MAXSIZE];
        case 10:
            return &VIBuffera[index - temp * MAXSIZE];
        case 11:
            return &VIBufferb[index - temp * MAXSIZE];
        case 12:
            return &VIBufferc[index - temp * MAXSIZE];
        case 13:
            return &VIBufferd[index - temp * MAXSIZE];
        case 14:
            return &VIBuffere[index - temp * MAXSIZE];
        case 15:
            return &VIBufferf[index - temp * MAXSIZE];
    }
    return &VIBuffer0[0];
}

double *getFFTRBuffer(int32_t index)
{
    uint32_t temp;
    temp = index / MAXSIZE;
    switch(temp){
        case 0:
            return &FFTRBuffer0[index];
        case 1:
            return &FFTRBuffer1[index - temp * MAXSIZE];
        case 2:
            return &FFTRBuffer2[index - temp * MAXSIZE];
        case 3:
            return &FFTRBuffer3[index - temp * MAXSIZE];
        case 4:
            return &FFTRBuffer4[index - temp * MAXSIZE];
        case 5:
            return &FFTRBuffer5[index - temp * MAXSIZE];
        case 6:
            return &FFTRBuffer6[index - temp * MAXSIZE];
        case 7:
            return &FFTRBuffer7[index - temp * MAXSIZE];
        case 8:
            return &FFTRBuffer8[index - temp * MAXSIZE];
        case 9:
            return &FFTRBuffer9[index - temp * MAXSIZE];
        case 10:
            return &FFTRBuffera[index - temp * MAXSIZE];
        case 11:
            return &FFTRBufferb[index - temp * MAXSIZE];
        case 12:
            return &FFTRBufferc[index - temp * MAXSIZE];
        case 13:
            return &FFTRBufferd[index - temp * MAXSIZE];
        case 14:
            return &FFTRBuffere[index - temp * MAXSIZE];
        case 15:
            return &FFTRBufferf[index - temp * MAXSIZE];
    }
    return &FFTRBuffer0[0];
}

double *getFFTIBuffer(int32_t index)
{
    uint32_t temp;
    temp = index / MAXSIZE;
    switch(temp){
        case 0:
            return &FFTIBuffer0[index];
        case 1:
            return &FFTIBuffer1[index - temp * MAXSIZE];
        case 2:
            return &FFTIBuffer2[index - temp * MAXSIZE];
        case 3:
            return &FFTIBuffer3[index - temp * MAXSIZE];
        case 4:
            return &FFTIBuffer4[index - temp * MAXSIZE];
        case 5:
            return &FFTIBuffer5[index - temp * MAXSIZE];
        case 6:
            return &FFTIBuffer6[index - temp * MAXSIZE];
        case 7:
            return &FFTIBuffer7[index - temp * MAXSIZE];
        case 8:
            return &FFTIBuffer8[index - temp * MAXSIZE];
        case 9:
            return &FFTIBuffer9[index - temp * MAXSIZE];
        case 10:
            return &FFTIBuffera[index - temp * MAXSIZE];
        case 11:
            return &FFTIBufferb[index - temp * MAXSIZE];
        case 12:
            return &FFTIBufferc[index - temp * MAXSIZE];
        case 13:
            return &FFTIBufferd[index - temp * MAXSIZE];
        case 14:
            return &FFTIBuffere[index - temp * MAXSIZE];
        case 15:
            return &FFTIBufferf[index - temp * MAXSIZE];
    }
    return &FFTIBuffer0[0];
}

//void UDMA_IRQHandler(void)
//{
//    transfer_count++;
//    if(transfer_count <= 15){
//        MAP_uDMAChannelTransferSet(UDMA_CH17_ADC0_3 | UDMA_PRI_SELECT,
//                                   UDMA_MODE_BASIC,
//                                   (void *)&ADC0->SSFIFO3, (void *)ADCBuffer0,
//                                   64);
//        MAP_uDMAChannelEnable(UDMA_CH17_ADC0_3);
//    }
//    else{
//        transfer_count = 0;
//        transfer_flag = 1;
//        MAP_uDMAChannelDisable(UDMA_CH17_ADC0_3);
//        MAP_uDMAChannelTransferSet(UDMA_CH17_ADC0_3 | UDMA_PRI_SELECT,
//                                   UDMA_MODE_BASIC,
//                                   (void *)&ADC0->SSFIFO3, (void *)ADCBuffer0,
//                                   64);
//    }
//}
void kfft(int32_t n,int32_t k)
{
  int32_t it,m,is,i,j,nv,l0;
  double p,q,s,vr,vi,poddr,poddi;
  vmin = 3.3;
  vmax = 0;
  for (it = 0; it <= n-1; it++)  //将pr[0]和pi[0]循环赋值给fr[]和fi[]
  {
      m=it;
      is=0;
      for(i=0; i<=k-1; i++)
      {
          j=m/2;
          is=2*is+(m-2*j);
          m=j;
      }
      *(getFFTRBuffer(it)) = (double)(*(getADCBuffer(is))  - v_ave) * 3.3 / 4096.0;
      *(getFFTIBuffer(it)) = 0;
      if(vmin > *(getFFTRBuffer(it))) vmin = *(getFFTRBuffer(it));
      if(vmax < *(getFFTRBuffer(it))){
          vmax = *(getFFTRBuffer(it));
          vmax_i = is;
      }
      *(getFFTRBuffer(it)) = *(getFFTRBuffer(it))  * hanning_1024[is];
  }
  *(getVRBuffer(0)) = 1.0;
  *(getVIBuffer(0)) = 0.0;
  p = 6.283185306 / (1.0 * n);
  *(getVRBuffer(1)) = cos(p); //将w=e^-j2pi/n用欧拉公式表示
  *(getVIBuffer(1)) = -sin(p);

  for (i=2; i<=n-1; i++)  //计算pr[]
  {
      p = *(getVRBuffer(i-1)) * *(getVRBuffer(1));
      q = *(getVIBuffer(i-1)) * *(getVIBuffer(1));
      s = (*(getVRBuffer(i-1)) + *(getVIBuffer(i-1)))*(*(getVRBuffer(1)) + *(getVIBuffer(1)));
      *(getVRBuffer(i)) = p - q;
      *(getVIBuffer(i)) = s - p - q;
  }

  for (it=0; it<=n-2; it=it+2)
  {
      vr = *(getFFTRBuffer(it));
      vi = *(getFFTIBuffer(it));
      *(getFFTRBuffer(it)) = vr + *(getFFTRBuffer(it + 1));
      *(getFFTIBuffer(it)) = vi + *(getFFTIBuffer(it + 1));
      *(getFFTRBuffer(it+1)) = vr - *(getFFTRBuffer(it + 1));
      *(getFFTIBuffer(it+1)) = vi - *(getFFTIBuffer(it + 1));
  }

  m=n/2;
  nv=2;
  for (l0=k-2; l0>=0; l0--) //蝴蝶操作
  {
      m=m/2;
      nv=2*nv;
      for (it=0; it<=(m-1)*nv; it=it+nv)
        for (j=0; j<=(nv/2)-1; j++)
          {
              p = *(getVRBuffer(m*j)) * *(getFFTRBuffer(it+j+nv/2));
              q = *(getVIBuffer(m*j)) * *(getFFTIBuffer(it+j+nv/2));
              s = *(getVRBuffer(m*j)) + *(getVIBuffer(m*j));
              s = s * (*(getFFTRBuffer(it+j+nv/2)) + *(getFFTIBuffer(it+j+nv/2)));
              poddr = p - q;
              poddi = s - p - q;
              *(getFFTRBuffer(it+j+nv/2)) = *(getFFTRBuffer(it+j)) - poddr;
              *(getFFTIBuffer(it+j+nv/2)) = *(getFFTIBuffer(it+j)) - poddi;
              *(getFFTRBuffer(it+j)) = *(getFFTRBuffer(it+j)) + poddr;
              *(getFFTIBuffer(it+j)) = *(getFFTIBuffer(it+j)) + poddi;
          }
  }
  magmax_i = 0;
  magmax = 0;
  for (i=0; i<=n/2-1; i++){
    *(getVRBuffer(i)) = sqrt(*(getFFTRBuffer(i)) * *(getFFTRBuffer(i)) + *(getFFTIBuffer(i)) * *(getFFTIBuffer(i)));  //幅值计算
    if(i >= 1 && magmax < *(getVRBuffer(i))){
      magmax =  *(getVRBuffer(i));
      magmax_i = i;
    }
 }
  return;
}
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
int main(void)
{
    int32_t i = 0;
    double v_out_temp;
    uint32_t systemClock;


    /* Configure the system clock for 120 MHz */
    systemClock = MAP_SysCtlClockFreqSet((SYSCTL_XTAL_25MHZ | SYSCTL_OSC_MAIN |
                                          SYSCTL_USE_PLL | SYSCTL_CFG_VCO_480),
                                          120000000);
    /* Initialize serial console */
    ConfigureUART2(systemClock);
    ConfigureUART7(systemClock);
    UARTStdioConfig(7, 38400, systemClock);
    UARTStdioConfig(2, 9600, systemClock);

    /* Enable the clock to GPIO Port N and wait for it to be ready */
    MAP_SysCtlPeripheralEnable(SYSCTL_PERIPH_GPION);
    while(!(MAP_SysCtlPeripheralReady(SYSCTL_PERIPH_GPION)))
    {
    }

    /* Configure PN0 as Output for controlling the LED */
    MAP_GPIOPinTypeGPIOOutput(GPIO_PORTN_BASE, GPIO_PIN_0);
    MAP_GPIOPinWrite(GPIO_PORTN_BASE, GPIO_PIN_0, ~(GPIO_PIN_0));

    /* Enable the clock to GPIO Port E and wait for it to be ready */
    MAP_SysCtlPeripheralEnable(SYSCTL_PERIPH_GPIOE);
    while(!(MAP_SysCtlPeripheralReady(SYSCTL_PERIPH_GPIOE)))
    {
    }

    /* Configure PE3 as ADC input channel */
    MAP_GPIOPinTypeADC(GPIO_PORTE_BASE, GPIO_PIN_2|GPIO_PIN_3);


    /* Enable the clock to ADC-1 and wait for it to be ready */
    MAP_SysCtlPeripheralEnable(SYSCTL_PERIPH_ADC1);
    while(!(MAP_SysCtlPeripheralReady(SYSCTL_PERIPH_ADC1)))
    {
    }

    /* Configure Sequencer 3 to sample the analog channel : AIN1. The
     * end of conversion and interrupt generation is set for AIN1 */
    MAP_ADCSequenceStepConfigure(ADC1_BASE, 3, 0, ADC_CTL_CH1 | ADC_CTL_IE |
                                 ADC_CTL_END);

    /* Enable sample sequence 3 with a timer trigger.  Sequence 3 will do a
     * single sample when the timer sends a signal to start the conversion */
    MAP_ADCSequenceConfigure(ADC1_BASE, 3, ADC_TRIGGER_PROCESSOR, 0);

    /* Since sample sequence 32 is now configured, it must be enabled. */
    MAP_ADCSequenceEnable(ADC1_BASE, 3);

    /* Clear the interrupt status flag.  This is done to make sure the
     * interrupt flag is cleared before we sample. */
    MAP_ADCIntClear(ADC1_BASE, 3);

    /* Enable the clock to ADC-0 and wait for it to be ready */
    MAP_SysCtlPeripheralEnable(SYSCTL_PERIPH_ADC0);
    while(!(MAP_SysCtlPeripheralReady(SYSCTL_PERIPH_ADC0)))
    {
    }


    /* Configure Sequencer 3 to sample a single analog channel : AIN0 */
    MAP_ADCSequenceStepConfigure(ADC0_BASE, 3, 0, ADC_CTL_CH0 | ADC_CTL_IE |
                                 ADC_CTL_END);

    /* Enable sample sequence 3 with a timer trigger.  Sequence 3 will do a
     * single sample when the timer sends a signal to start the conversion */
    MAP_ADCSequenceConfigure(ADC0_BASE, 3, ADC_TRIGGER_TIMER, 3);

    /* Clear the interrupt status flag before enabling. This is done to make
     * sure the interrupt flag is cleared before we sample. */
    MAP_ADCIntClearEx(ADC0_BASE, ADC_INT_DMA_SS3);
    MAP_ADCIntEnableEx(ADC0_BASE, ADC_INT_DMA_SS3);

    /* Clear the interrupt status flag.  This is done to make sure the
     * interrupt flag is cleared before we sample. */
    MAP_ADCIntClear(ADC0_BASE, 3);

    /* Enable the DMA request from ADC0 Sequencer 3 */
    MAP_ADCSequenceDMAEnable(ADC0_BASE, 3);

    /* Since sample sequence 3 is now configured, it must be enabled. */
    MAP_ADCSequenceEnable(ADC0_BASE, 3);


    /* Enable the DMA and Configure Channel for TIMER0A for Ping Pong mode of
     * transfer */
    MAP_SysCtlPeripheralEnable(SYSCTL_PERIPH_UDMA);
    while(!(SysCtlPeripheralReady(SYSCTL_PERIPH_UDMA)))
    {
    }

    MAP_uDMAEnable();

    /* Point at the control table to use for channel control structures. */
    MAP_uDMAControlBaseSet(pui8ControlTable);

    /* Map the ADC0 Sequencer 3 DMA channel */
    MAP_uDMAChannelAssign(UDMA_CH17_ADC0_3);

    /* Put the attributes in a known state for the uDMA ADC0 Sequencer 2
     * channel. These should already be disabled by default. */
    MAP_uDMAChannelAttributeDisable(UDMA_CH17_ADC0_3,
                                    UDMA_ATTR_ALTSELECT | UDMA_ATTR_USEBURST |
                                    UDMA_ATTR_HIGH_PRIORITY |
                                    UDMA_ATTR_REQMASK);

    /* Configure the control parameters for the primary control structure for
     * the ADC0 Sequencer 2 channel. The primary control structure is used for
     * copying the data from ADC0 Sequencer 2 FIFO to srcBuffer. The transfer
     * data size is 16 bits and the source address is not incremented while
     * the destination address is incremented at 16-bit boundary.
     */
    MAP_uDMAChannelControlSet(UDMA_CH17_ADC0_3 | UDMA_PRI_SELECT,
                              UDMA_SIZE_16 | UDMA_SRC_INC_NONE | UDMA_DST_INC_16 |
                              UDMA_ARB_1);

    /* Set up the transfer parameters for the ADC0 Sequencer 3 primary control
     * structure. The mode is Basic mode so it will run to completion. */
    MAP_uDMAChannelTransferSet(UDMA_CH17_ADC0_3 | UDMA_PRI_SELECT,
                               UDMA_MODE_BASIC,
                               (void *)&ADC0->SSFIFO3, (void *)ADCBuffer,
                               1024);


    /* Enable Timer-0 clock and configure the timer in periodic mode with
     * a frequency of 1 KHz. Enable the ADC trigger generation from the
     * timer-0. */
    MAP_SysCtlPeripheralEnable(SYSCTL_PERIPH_TIMER0);
    while(!(MAP_SysCtlPeripheralReady(SYSCTL_PERIPH_TIMER0)))
    {
    }

    MAP_TimerConfigure(TIMER0_BASE, TIMER_CFG_A_PERIODIC);
    MAP_TimerLoadSet(TIMER0_BASE, TIMER_A, (systemClock/1100000));
    MAP_TimerADCEventSet(TIMER0_BASE, TIMER_ADC_TIMEOUT_A);
    MAP_TimerControlTrigger(TIMER0_BASE, TIMER_A, true);

    while(1)
    {
        if(circle_count == 0){
            uart_temp = MAP_UARTCharGetNonBlocking(UART7_BASE);
            if(uart_temp == 0xAA){
                circle_count = 10;
                MAP_TimerLoadSet(TIMER0_BASE, TIMER_A, (systemClock/1100000)); //初始化采样率
                sample_rate = 1000000.0;
            }
        }
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

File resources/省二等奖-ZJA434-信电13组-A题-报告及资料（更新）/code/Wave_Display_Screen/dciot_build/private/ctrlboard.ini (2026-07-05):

[tcpip]

dhcp=n

ipaddr=192.168.1.100

netmask=255.255.255.0

gw=192.168.1.1

dns=192.168.1.1

server_port=5050

remote_ip=192.168.1.200

network_transfer=0

network_mode=0



[ctrlboard]

lcd_width=1024

lcd_height=600

baudrate=38400

enable_keysound=0

audiolevel=100



[wifi]

wifi_mode=0

ssid=

password=

secumode=0

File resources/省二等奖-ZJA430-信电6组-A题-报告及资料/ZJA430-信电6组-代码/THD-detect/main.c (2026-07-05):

#define _MAIN_C_
#include "main.h"

void do_sdwa_update(void)
{
    uint8_t data[PBUFFERSIZE * 2] = {0};
    SDWa_InstrInfo a;
    int i, j = 0;
    u16 tmp;

    for (i = 0; i < PBUFFERSIZE; i++)
    {
        tmp = pBuffer[i];
        data[j++] = tmp >> 8;
        data[j++] = tmp & 0xff;
    }

    a.instr = CURV;
    a.CH_Mode = 1 << 0;
    a.fhead = 0xa55a;
    a.data_len = PBUFFERSIZE;
    a.data_ptr = data;
    SDWa_SendCurve(a);

    for (i =1;i<5;i++){
        a.instr = WVAR;
        a.start_addr = i;
        a.data_len = 1;
        tmp = Uo[i]*1000/Uo[0];
        data[0]=tmp >> 8;
        data[1]=tmp & 0xff;
        a.data_ptr = data;
        SDWa_Build(a);
        SDWa_Send();
    }

    a.start_addr = 5;
    tmp = THDx*10000;
    data[0]= tmp >> 8;
    data[1]=tmp & 0xff;
    a.data_ptr = data;
    SDWa_Build(a);
    SDWa_Send();

    u32 tmp1;
    a.start_addr = 6;
    tmp1 = BaseFreqDisp;
    a.data_len = 2;
    data[0]= tmp1 >> 24;
    data[1]=(tmp1>>16) & 0xff;
    data[2]=(tmp1>>8) & 0xff;
    data[3]=tmp1 & 0xff;
    a.data_ptr = data;
    SDWa_Build(a);
    SDWa_Send();
}

void do_tcp_update(void)
{
    int len=-1;
    char msg[4096];
    uint16_t uamp[4];
    int i;
    for(i=1;i<5;i++)
        uamp[i-1]=Uo[i]*1000/Uo[0];
    len = sprintf(msg,"BaseFreq=%u,THD=%u,%u,%u,%u,%u:",BaseFreq,(uint32_t)(THDx*10000),
                    uamp[0],uamp[1],uamp[2],uamp[3]);
    tcp_send(0,msg,len);
//    UARTprintf("--TCP--Send %d bytes\r\n", len);

//    for(i=0;i<PBUFFERSIZE;i++)
//    {
//        len = sprintf(msg, "%u,",pBuffer[i-1]);
//        tcp_send(0,msg,len);
//    }
//    UARTprintf("--TCP--Send %d bytes\r\n", len);
}

void draw_wave_buf(void)
{
    int i;
    float base;
    float composite;
    float sum=0;
    for(i=0;i<5;i++)
    {
        sum+=Uo[i];
    }
    if(sum<1e-5)
        return;
    for(i=0;i<PBUFFERSIZE;i++)
    {
        base = 2*PI/PBUFFERSIZE*i;
        composite = Uo[0]*sin(base)+  Uo[1]*sin(2*base)+
                    Uo[2]*sin(3*base)+Uo[3]*sin(4*base)+
                    Uo[4]*sin(5*base);
        pBuffer[i] = (composite+sum)/(2*sum)*4095;
    }
}

void update_wave_buf(void)
{
    int i;
    uint32_t save_SampleFreq = SampleFreq;
    uint32_t plimit=PBUFFERSIZE;
    SampleFreq = (PBUFFERSIZE/1)*BaseFreq;
    if(SampleFreq > 1e6)
    {
        SampleFreq = 1e6;
        plimit = SampleFreq/BaseFreq;
    }
//    UARTprintf("F_wavesample=%u, plimit=%u\r\n",SampleFreq, plimit);

    ADC_Sample();
    SampleFreq = save_SampleFreq;

    if(plimit==PBUFFERSIZE)
    {
//        UARTprintf("draw full\r\n");
        for(i=0;i<PBUFFERSIZE;i++)
            pBuffer[i]=adcBuffer[i+10];
    }
    else
    {
//        UARTprintf("draw interp\r\n");
        // 线性插值
        float delta = 1.0*plimit/PBUFFERSIZE;
        uint16_t a,b;
        for(i=0;i<PBUFFERSIZE;i++)
        {
            a = adcBuffer[(uint16_t)(i*delta)+10];
            b = adcBuffer[(uint16_t)(i*delta)+11];
            pBuffer[i] = a+(b-a)*(i*delta - (uint16_t)(i*delta));
        }
//        pBuffer[PBUFFERSIZE-1] = adcBuffer[plimit-1];
    }
    // auto scale
    uint16_t pmax=pBuffer[0];
    uint16_t pmin=pBuffer[0];
    double scale;
    for(i=0;i<PBUFFERSIZE;i++)
        if(pmax<pBuffer[i])
            pmax = pBuffer[i];
        else if(pmin>pBuffer[i])
            pmin=pBuffer[i];
    scale = pmax-pmin;
    if((scale)>1e-4)
        for(i=0;i<PBUFFERSIZE;i++)
            pBuffer[i]=(pBuffer[i]-pmin)*(4095)/scale;

    // debug
//    for(i=0;i<PBUFFERSIZE;i++)
//        UARTprintf("%d,\r\n",pBuffer[i]);
//    UARTprintf("\r\n");
}

void board_init(void)
{
    // variable init
    sdwa_send_flag = 0;
    sdwa_recv_flag = 0;
    systemClock = MAP_SysCtlClockFreqSet((SYSCTL_XTAL_25MHZ | SYSCTL_OSC_MAIN |
                                          SYSCTL_USE_PLL | SYSCTL_CFG_VCO_480),
                                          120000000);
    // enable interrupt
    MAP_IntMasterEnable();
    // device init
    SDWa_UartInit();
    esp8266_init();

}

void compute_base_freq(void)
{
    uint32_t ii, base_flag;
    SampleFreq = 1e6;
    base_flag = 0;
    while(1)
    {
        ADC_Sample();

        /* First convert the sampled data to floating point format as the RMS
         * and DC average is being computed */
        for(ii=0;ii<NPT;ii++)
        {
            fft_in[ii] = 3.3*adcBuffer[ii]/4095;
//            UARTprintf("%d,\r\n", (uint32_t)fft_in[ii]*1000);
//            UARTprintf("%d,", adcBuffer[ii]);
        }
        //
        FFT(fft_out, fft_in, NPT);
        Get_Mag(fft_in, fft_out, NPT);

        for(ii = 0; ii<NPT/2; ii++)
        {
            if(!ii)
                fft_in[ii] = fft_in[ii]/NPT;
            else
            {
                fft_in[ii] = fft_in[ii]/NPT*2;
            }
        }

        Find_Fund(fft_in, NPT, &base_freq_index);
        BaseFreq = base_freq_index*SampleFreq/NPT;
        if(base_flag)  break;

        if(BaseFreq < 1e6/50 )
        {
            SampleFreq = 50*BaseFreq;
            base_flag++;
        }
        else if(BaseFreq < 1e6/20 )
        {
            SampleFreq = 20*BaseFreq;
            base_flag++;
        }
        else if(BaseFreq < 1e6/10 )
        {
            SampleFreq = 10*BaseFreq;
            base_flag++;
        }
        else
            break;
    }
//    UARTprintf("\r\nFs=%d,BaseFreq=%d\r\n",SampleFreq,  BaseFreq);
    BaseFreqDisp = BaseFreq;
    BaseFreq = (uint32_t)((float)BaseFreq/1000.0 + 0.5)*1000;
}

float compute_THD_goertzel(void)
{
    struct goertzel_state g;
    float sum=0;
    float thd = 0.0;
    int i,s;
    uint16_t num_periods = BaseFreq * NPT / SampleFreq;
    if(num_periods>10)
        num_periods = 10;
    uint16_t npoints = num_periods*SampleFreq/BaseFreq;
//    UARTprintf("--G--npoints = %u\r\n",npoints);
    for(i=0;i<5;i++)
    {
        goertzel_reset(&g);
        goertzel_init(&g, SampleFreq, BaseFreq*(i+1), npoints);
        for(s = 0; s < npoints; s++)
        {
            goertzel_process_sample(&g, (goertzel_storage_type)(adcBuffer[s]*3300.0/4095.0));
        }
        Uo[i] = goertzel_get_magnitude(&g)/npoints*2;
        if(i!=0)sum += Uo[i]*Uo[i];
//        UARTprintf("--G--%d Hz -> %d uV\r\n", BaseFreq*(i+1), (int)(Uo[i]*1000));
    }
    if(Uo[0]>1e-4)
        thd = sqrt(sum)/Uo[0];
//    UARTprintf("--G--thd = %u/1000\r\n",(uint32_t)(thd*1000));

//    for(s = 0; s < npoints; s++)
//    {
//        UARTprintf("AAAA%u,\r\n",adcBuffer[s]);
//    }
    return thd;
}

float compute_THD_fft(void)
{
    int i;
    uint32_t idx[4];
    float sum = 0;
    float thd = 0.0;
    for(i=2;i<6;i++)
    {
        Center_Find(fft_in,base_freq_index*i,idx+i-2);
    }
    Uo[0]=fft_in[base_freq_index];
    for(i=1;i<5;i++)
    {
        Uo[i]=fft_in[idx[i-1]];
        sum += Uo[i]*Uo[i];
    }

    if(Uo[0]>1e-4)
        thd = sqrt(sum)/Uo[0];
//    UARTprintf("--FFT--THDx = %u/1000\r\n",(uint32_t)(THDx*1000));
    return thd;
}
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

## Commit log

2026-07-05 refactor: add framework
2026-07-07 feat: add hardware
    [2021.PcbDoc, 2021.PrjPcb, 2021.SchDoc]
2026-07-07 feat: add thd calculating
    [2021.PrjPcb]
2026-07-07 feat: 重建波形显示
2026-07-07 feat: dds模块驱动
2026-07-07 删除ternimal模块
2026-07-08 绘制原理图
    [2021.SchDoc, 21A.PcbDoc]
2026-07-09 完成布局
    [2021.PcbDoc, 2021.PrjPcb, 2021.SchDoc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]
2026-07-09 pcb完成
    [2021.SchDoc, 21A.PcbDoc]
2026-07-10 app初版，功能完整。
    [2021.PcbDoc, 2021.PrjPcb, 21A.PcbDoc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]
2026-07-13 加窗函数，增大fft点数，采样率自适应算法，指数平均计算结果去除噪声
    [2021.SchDoc, 21A.PcbDoc, buffer.PcbDoc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]
2026-07-14 增大ema系数，等待时间减少，autofs加快
2026-07-14 差分法尝试
2026-07-15 基频提取采用固定采样率，不再动态变化
2026-07-16 报告初版
2026-07-17 完成报告
    [2021.PrjPcb, 2021.SchDoc, 21A.PcbDoc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]
2026-07-24 删除无用文件
